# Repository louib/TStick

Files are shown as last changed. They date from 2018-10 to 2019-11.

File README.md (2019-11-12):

# T-Stick Digital Musical Instrument (DMI)

The T-Stick is a DMI conceived by Joseph Malloch and D. Andrew Stewart at the Input Devices and Music Interaction Laboratory (IDMIL) at McGill University. It has been in development since 2006, has a relatively long history for a DMI, has multiple versions, several expert performers, and has an associated repertoire. More than 20 copies have been built unintended for commercial use. Nevertheless, it has been adopted by expert performers and composers as part of their musical practice including D. Andrew Stewart (Soprano user) and Fernando Rocha (Tenor user). It has appeared in dozens of public appearances in countries such as Canada, USA, Brazil, Italy, Norway, and Portugal.

This repository hosts up to date firmware for the instruments currently  at the IDMIL. Driver and Instrument patches in Max/MSP. Spec Sheets and Schematics for all instruments.

## Documentation:

[T-Stick connection guide – v1.1 for wireless T-Sticks](./Sopranino/2GW/FW19101/Docs/T-Stick_2GW_Connecting_Guide(v1.1).md) (model [2GW-19X](./Sopranino/2GW/FW19101/README.md))

[How to build a T-Stick Sopranino](./Sopranino/2GW/FW19101/Docs/T-Stick_2GW_building_instructions.md)

## Instruments:

As of October 2019 there are 13 instruments at [IDMIL](http://www.idmil.org):

- 01 T-Stick Tenor (2G)
- 06 T-Stick Sopranos (2G, 2GX, 2G-IMU)
- 01 T-Stick Sopranino (2G)
- 05 wireless T-Stick Sopraninos (2G, 2GW)

## Project info:

Project webpage at IDMIL: http://www-new.idmil.org/project/the-t-stick/

Official repository: https://github.com/IDMIL/TStick

IDMIL - Input Devices and Music Interaction Laboratory - http://www-new.idmil.org/ \
CIRMMT - Centre for Interdisciplinary Research in Music Media and Technology - http://www.cirmmt.org/ \
Schulich School of Music - McGill University

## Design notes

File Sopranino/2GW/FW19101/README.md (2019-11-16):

# T-Stick 2GW (Firmware version: 19101)

- [Firmware upload instructions](#firmware-upload-instructions)
	* [Option 1: using .bin files and esptool.py](#option-1-using-bin-files-and-esptoolpy)
	* [Option 2: Using Arduino IDE](#option-2-using-arduino-ide)
- [Other Documentation](#other-documentation)
- [Firmware information](#firmware-information)

##  Firmware upload instructions:

###  Option 1: using .bin files and esptool.py

This method is easier/faster. It uses [esptool.py](https://github.com/espressif/esptool). 

##### Download [esptool.py](https://github.com/espressif/esptool):

- Download the _esptool.py_ from https://github.com/espressif/esptool. Use the `Download ZIP` option from Github
- Unzip the _esptool-master.zip_ file

##### Connect the T-Stick to the computer and check the USB port:

- [Check the T-Stick (ESP32) port in your computer](https://docs.espressif.com/projects/esp-idf/en/latest/get-started/establish-serial-connection.html):
  - For MacOS/Linux:
    - Open a _Terminal_ window
    - Execute the command `ls /dev/cu.*`. The command will return a list of ports in your computer.
    - Plug the T-Stick (USB) and run the command `ls /dev/cu.*` one more time. You can now compare the lists and anotate the T-Stick USB port. Should be something similar to `/dev/cu.wchusbserial1410`, probably with a different number
    - Linux users should also give the currently logged user read and write access the serial port over USB.
      Check [here](https://docs.espressif.com/projects/esp-idf/en/latest/get-started/establish-serial-connection.html) for more information
  - For Windows:
    - Check the list of identified COM ports in the [Windows Device Manager](https://support.microsoft.com/en-ca/help/4026149/windows-open-device-manager)
    - Plug the T-Stick (USB) and check the list of identified COM ports in the [Windows Device Manager](https://support.microsoft.com/en-ca/help/4026149/windows-open-device-manager) again. The T-Stick port should appear on the list. Anotate the T-Stick USB port, it should be something similar to `COM3` or `COM16`

##### Flash the firmware (.bin files):

- Use _Finder_ or _Terminal_ to copy the contents of the [bin](./bin/) folder (you should copy 5 .bin files) to the _esptool-master_ folder
- Navigate to the _esptool-master_ folder in _Terminal_
- Run the command (__don't forget to replace the --port (/dev/cu.wchusbserial1410) option for your T-Stick port__):
  ````
  esptool.py --chip esp32 --port /dev/cu.wchusbserial1410 --baud 115200 --before default_reset --after hard_reset write_flash -z --flash_mode dio --flash_freq 80m --flash_size detect 0xe000 boot_app0.bin 0x1000 bootloader_dio_80m.bin 0x10000 esp32_arduino_19X_19101.ino.bin 0x8000 esp32_arduino_19X_19101.ino.partitions.bin 2686976 esp32_arduino_19X_19101.spiffs.bin
  ```
  Wait for the process to be complete. Do not unplug or turn off your T-Stick during the process.
- Your T-Stick will have default information. You need to connect with the instrument (see the [T-Stick Connecting Guide](./Docs/T-Stick_2GW_Connecting_Guide(v1.1).md)) and change all basic information (device name, author, nickname, and id)

To test if the data is being send correctly:

- Connect the T-Stick to a network (instructions [here](./Docs/T-Stick_2GW_Connecting_Guide(v1.1).md));
- Open the Pure Data (PD) or Max/MSP patch to receive T-Stick messages (they can be found [here](./Configuration));
- Start receive OSC messages according to the chosen patch.

###  Option 2: Using Arduino IDE

_READ ALL DEPENDENCIES AND OBSERVATIONS BEFORE UPLOAD !_

##### Install Arduino IDE:

To download and install Arduino IDE, follow the instructions at https://www.arduino.cc/en/main/software.

##### Install Arduino ESP32 filesystem uploader: 

You need to upload a file (data/config.json) into ESP32 filesystem. 
Follow the instructions at https://github.com/me-no-dev/arduino-esp32fs-plugin.

##### Install all depencencies:

1. ESP32 Arduino core 1.0.4 or newer. Instructons at https://github.com/espressif/arduino-esp32/blob/master/docs/arduino-ide/boards_manager.md. Install using [boards manager](https://www.arduino.cc/en/guide/cores)
2. For some systems it may be required to also install the ESP8266 Arduino core. Instructons at https://github.com/esp8266/Arduino. Install using [boards manager](https://www.arduino.cc/en/guide/cores)
3. [Wifi32Manager](https://github.com/edumeneses/WiFi32Manager). Instructons at https://github.com/edumeneses/WiFi32Manager#installing. Install using [manual installation](https://www.arduino.cc/en/guide/libraries#toc5)
4. [Adafruit_LSM9DS1](https://github.com/adafruit/Adafruit_LSM9DS1). Install using [library manager](https://www.arduino.cc/en/guide/libraries#toc3)
5. [ArduinoJSON](https://github.com/bblanchon/ArduinoJson) v6.12 or up. Install using [library manager](https://www.arduino.cc/en/guide/libraries#toc3)
6. [CNMAT OSC library](https://github.com/CNMAT/OSC) v3.5.7 or up. Install using [library manager](https://www.arduino.cc/en/guide/libraries#toc3)
7. [DocSunset MIMU Library](https://github.com/DocSunset/MIMU). Install using [manual installation](https://www.arduino.cc/en/guide/libraries#toc5)
8. [Eigen linear algebra library for Arduino](https://github.com/bolderflight/Eigen). Install using [manual installation](https://www.arduino.cc/en/guide/libraries#toc5)

Observations:

1. MINU library complains if you keep any IMU-related files other than MIMU_LSM9DS1.h and MIMU_LSM9DS1.cpp
2. Microcontroller currently in use for T-Stick 2GW: [Wemos LOLIN D32 PRO](https://wiki.wemos.cc/products:d32:d32_pro)

##### Create your custom config.json file:

Each T-Stick uses a _config.json_ file to store all configuration paramethers.

- Make the necessary changes to the [_config.json_](./esp32_arduino_19X_19101/data/config.json) file:
  - device: replace _color_ with the shrinking material color, and _19X_ with T-stick's serial number
  - author: replace _IDMIL_ with the builder's name (or alias)
  - nickname: replace _color_ with the shrinking material color
  - id: replace _190_ with your T-Stick serial number
- Save the file at the _data_ folder (inside _esp32_arduino_19X_19101_). Make sure _config.json_ is the only file at _data_ folder

##### Upload (flash) the firmware and config.json into the T-Stick:

- Open the file `esp32_arduino_19X_19101.ino` using Arduino IDE
- Choose the proper _board_: `Tools -> Board: "*******" -> LOLIN D32 PRO`
- Choose Upload Speed: `Tools -> Upload Speed: "******" -> 115200`
- Choose port:
  - Keep the T-Stick disconnected to the computer
  - Go to: `Tools -> Port` and take note the available ports
  - connect the T-Stick to the computer using an USB cable and turn the T-Stick ON
  - Go to: `Tools -> Port` and choose the new available port (T-Stick port)
- Upload the firmware: `Sketch -> Upload`. Do not disconnect or turn the T-Stick off during the upload process
- Upload _config.json_: `Tools -> ESP32 Sketch Data Upload`. Do not disconnect or turn the T-Stick off during the upload process

##### Test T-Stick:

To test your T-Stick after flashing firmware/config.json, you can use Arduino IDE:

- Choose T-Stick serial port
- Open the _Serial Monitor_ (`Tools -> Serial Monitor`)

You should see T-Stick booting process.

To test if the data is being send correctly:

- Connect the T-Stick to a network (instructions [here](./Docs/T-Stick_2GW_Connecting_Guide(v1.1).md))
- Open the Pure Data (PD) or Max/MSP patch to receive T-Stick messages (they can be found [here](./Configuration))
- Start receive OSC messages according to the chosen patch

##  Other Documentation:

[T-Stick connection guide – v1.1 for wireless T-Sticks](./Docs/T-Stick_2GW_Connecting_Guide(v1.1).md) (model 2GW-19X)

[How to build a T-Stick Sopranino](./Docs/T-Stick_2GW_building_instructions.md)

##  Firmware information:

Sopranino T-Stick 2GW - LOLIN D32 PRO - USB -WiFi  
Input Devices and Music Interaction Laboratory (IDMIL)  
Created: February 2018 by Alex Nieva  
October 2019 by Edu Meneses - firmware version 19101 (2019-10.v1)  
Notes: Based on test program for reading CY8C201xx using I2C by Joseph Malloch 2011  
Adapted to work with Arduino IDE 1.8.10 and T-Stick Sopranino 2GW  

WiFi32Manager - For use with ESP8266 or ESP32  
Created originally for the T-Stick project:  
http://www-new.idmil.org/project/the-t-stick/  
This code uses code (fork) of 3 other projects:  
https://github.com/kentaylor/WiFiManager    
https://github.com/tzapu/WiFiManager  
https://github.com/zhouhan0126/WIFIMANAGER-ESP32    
Edu Meneses - IDMIL - Mar 2019    

MIMU - Magnetometer + accelerometer + gyroscope orientation library  
https://github.com/DocSunset/MIMU  
Travis West - IDMIL - Oct 2019

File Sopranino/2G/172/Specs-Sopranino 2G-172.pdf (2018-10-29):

## T-Stick Sopranino 2G

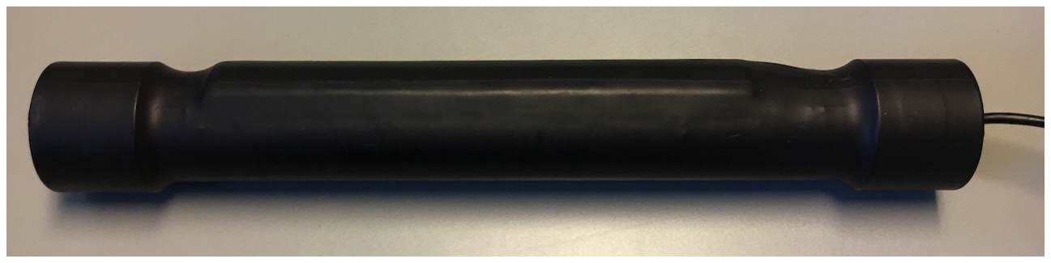
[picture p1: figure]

Specifications:

- Touch Sensing: 16 capacitive sensing strips
- Motion Sensing: 3-axis digital accelerometer
- Pressure Sensing: 1 Force Sensitive Resistor
- Shock Sensing: 1 Piezoelectric senor
- Connectivity: USB 2.0 Mini Type-B
- Dimensions: 35cm x 5cm (diameter)
- Weight: 0.311 Kg
- Serial Number: 172

Requirements:

- Mac OSX with Max/MSP
- Libmapper externals for Max/MSP
- Sound Synthesizers that work with libmapper: granul8, modal.
- Other sound synthesizers to create ad-hoc mappings.

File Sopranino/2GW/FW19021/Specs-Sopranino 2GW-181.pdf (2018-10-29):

## T-Stick Sopranino 2GW

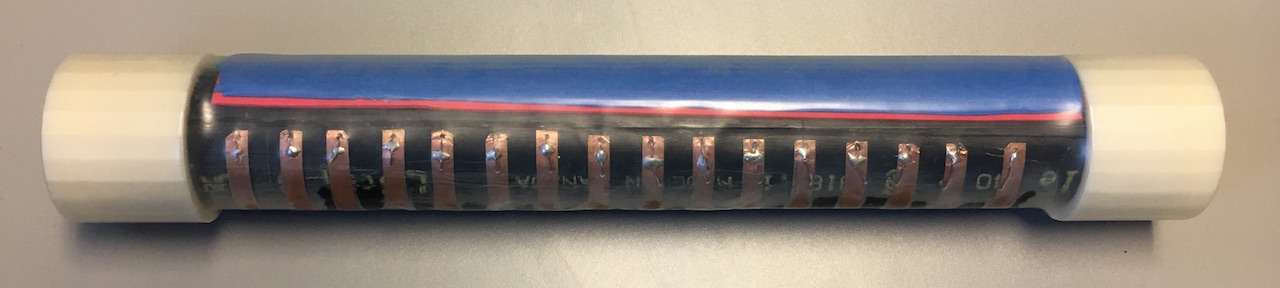
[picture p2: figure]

Specifications:

- Touch Sensing: 16 capacitive sensing strips
- Motion Sensing: 9 DOF IMU
- Pressure Sensing: 1 Force Sensitive Resistor
- Connectivity: WiFi – OSC based data communication
- Dimensions: 33.5cm x 5cm (diameter)
- Weight: 0.3 Kg
- Serial Number: 181

Requirements:

- Mac OSX with Max/MSP
- Libmapper externals for Max/MSP
- Sound Synthesizers that work with libmapper: granul8, modal.
- Other sound synthesizers to create ad-hoc mappings.

OSC Namespace

Send | Variable type
/information | (2) unsigned int
/rawcapsense | (2) int
/rawgyro | (3) float
/rawaccel | (3) float
/rawmag | (3) float
/rawpressure | (1) unsigned int

Receive | Variable type/Description
/status | (4) int
/status 115 | Heartbeat every 1.5sec
/status 120 | Stop
/status 119 105 i i | Write info: Serial #, Firmware Rev.
/status 119 84 i i | Touch Mask
/status 99 i | Calibration of FSR
/status 119 119 | Write Settings EEPROM
/status 119 114 | Read Settings EEPROM

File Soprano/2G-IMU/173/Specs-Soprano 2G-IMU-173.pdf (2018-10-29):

## T-Stick Soprano 2G-IMU

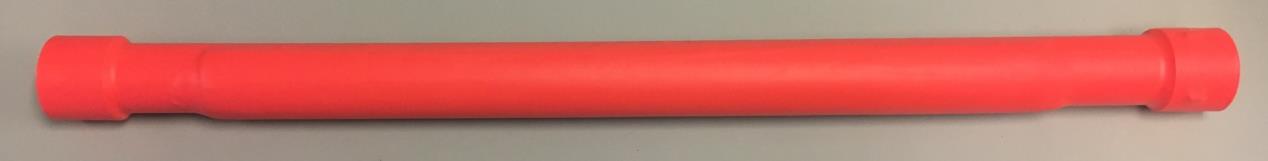
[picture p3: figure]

Specifications:

- Touch Sensing: 48 capacitive sensing strips
- Motion Sensing: 9 DOF IMU
- Pressure Sensing: 1 Force Sensitive Resistor (paper-based)
- Shock Sensing: 1 Piezoelectric sensor
- Connectivity: USB 2.0 Type-B
- Dimensions: 71cm x 5cm (diameter)
- Weight: 0.595 Kg
- Serial Number: 173

Requirements:

- Mac OSX with Max/MSP
- Libmapper externals for Max/MSP
- Sound Synthesizers that work with libmapper: granul8, modal.
- Other sound synthesizers to create ad-hoc mappings.

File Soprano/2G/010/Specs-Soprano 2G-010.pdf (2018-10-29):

## T-Stick Soprano 2G

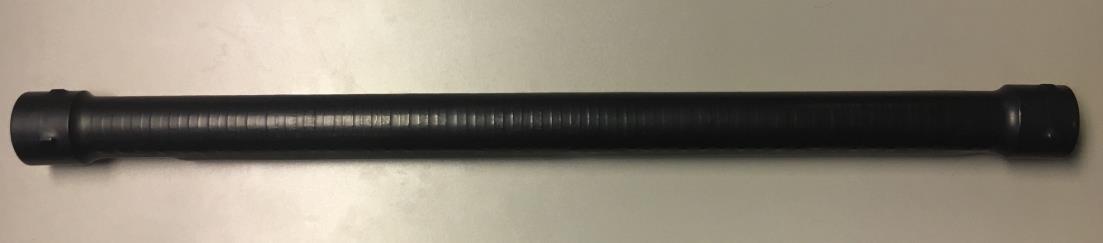
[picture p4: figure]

Specifications:

- Touch Sensing: 48 capacitive sensing strips
- Motion Sensing: 3-axis analogue accelerometer
- Pressure Sensing: 1 Force Sensitive Resistor
- Shock Sensing: 1 Piezoelectric sensor
- Connectivity: USB 2.0 Type-B
- Dimensions: 71cm x 5cm (diameter)
- Weight: 0.571 Kg
- Serial Number: 010

Requirements:

- Mac OSX with Max/MSP
- Libmapper externals for Max/MSP
- Sound Synthesizers that work with libmapper: granul8, modal.
- Other sound synthesizers to create ad-hoc mappings.

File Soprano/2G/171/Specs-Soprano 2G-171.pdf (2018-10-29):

## T-Stick Soprano 2G

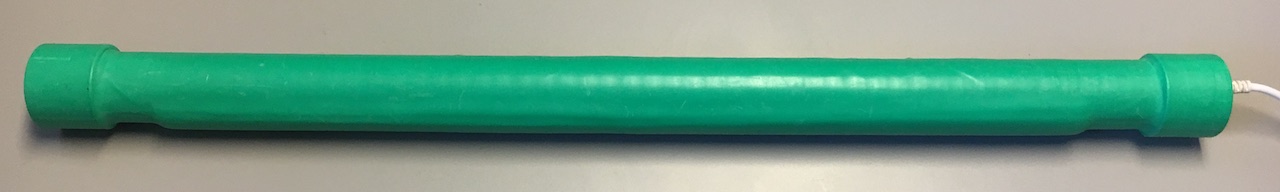
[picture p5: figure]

Specifications:

- Touch Sensing: 48 capacitive sensing strips
- Motion Sensing: 3-axis analog accelerometer
- Pressure Sensing: 1 Force Sensitive Resistor
- Shock Sensing: 1 Piezoelectric sensor
- Connectivity: USB 2.0 Type-B
- Dimensions: 71cm x 5cm (diameter)
- Weight: 0.606 Kg
- Serial Number: 171

Requirements:

- Mac OSX with Max/MSP
- Libmapper externals for Max/MSP
- Sound Synthesizers that work with libmapper: granul8, modal.
- Other sound synthesizers to create ad-hoc mappings.

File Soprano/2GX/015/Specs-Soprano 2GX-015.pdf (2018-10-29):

## T-Stick Soprano 2GX

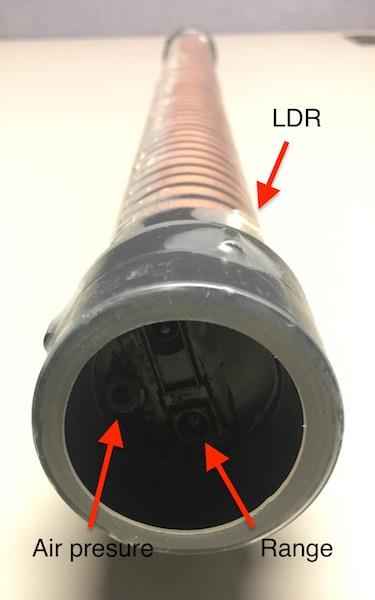
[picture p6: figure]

Specifications:

- Touch Sensing: 48 capacitive sensing strips
- Motion Sensing: 3-axis digital accelerometer
- Pressure Sensing: 1 Force Sensitive Resistor
- Shock Sensing: 1 Piezoelectric sensor
- Light Sensing: 2 LDRs
- Range Sensing: Infrared
- Breath Sensing: Air pressure sensor
- Connectivity: USB 2.0 Type-B
- Dimensions: 71cm x 5cm (diameter)
- Weight: 0.597 Kg
- Serial Number: 171

Requirements:

- Mac OSX with Max/MSP
- Libmapper externals for Max/MSP
- Sound Synthesizers that work with libmapper: granul8, modal.
- Other sound synthesizers to create ad-hoc mappings.

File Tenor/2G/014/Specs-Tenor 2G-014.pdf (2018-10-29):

## T-Stick Tenor 2G

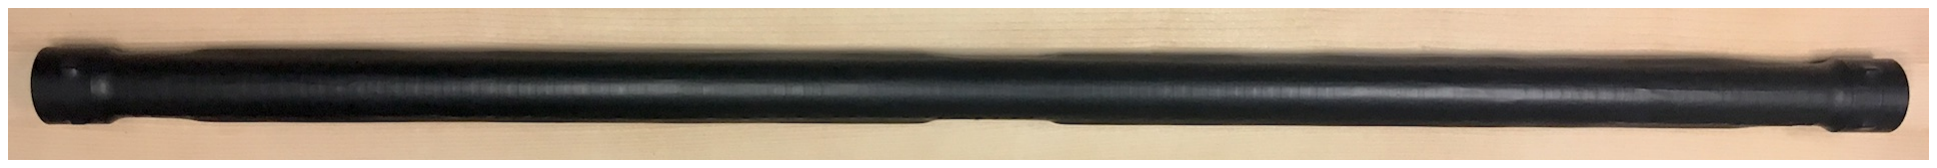
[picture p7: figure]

Specifications:

- Touch Sensing: 96 capacitive sensing strips
- Motion Sensing: 3-axis accelerometer
- Pressure Sensing: 1 Force Sensitive Resistor
- Shock Sensing: 1 Piezoelectric sensor
- Connectivity: USB 2.0 Type-B
- Dimensions: 124.5cm x 5cm (diameter)
- Weight: 0.976 Kg
- Serial Number: 014

Requirements:

- Mac OSX with Max/MSP
- Libmapper externals for Max/MSP
- Sound Synthesizers that work with libmapper: granul8, modal.
- Other sound synthesizers to create ad-hoc mappings.

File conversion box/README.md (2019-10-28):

# T-Stick Conversion Box - Building recipe - Rpi 2B and 3B+

Under Raspbian Lite

## Prepare the OS

- Flash the latest Prynth image (https://prynth.github.io/create/downloads.html)
- Add ssh file to Boot partition: `touch ssh`
- Add wpa_supplicant.conf to file to Boot partition: `vim wpa_supplicant.conf`. File contents:

```bash
ctrl_interface=DIR=/var/run/wpa_supplicant GROUP=netdev
update_config=1
country=US

network={
     ssid="Your network name/SSID"
     psk="Your WPA/WPA2 security key"
     key_mgmt=WPA-PSK
}
```

- Open Prynth software settings at `http://raspberrypi.local:3000/system` and change hostname to match the converted T-Stick  
- SSH, change password, hostname, set country, expand file system (raspi-config)

## Update

```bash
sudo apt-get -y update
sudo apt-get -y dist-upgrade
```

## Install liblo

```bash
sudo apt-get remove -y liblo-dev
mkdir ~/sources
cd ~/sources
git clone https://github.com/radarsat1/liblo.git
cd liblo
sudo apt-get install -y vim autoconf libtool automake
./autogen.sh
make
sudo make install
```

## Install Libmapper

```bash
sudo apt-get install python-dev swig
cd ~/sources
git clone https://github.com/libmapper/libmapper.git
cd libmapper
./autogen.sh
echo 'export LD_LIBRARY_PATH=$LD_LIBRARY_PATH:/usr/local/lib' >> ~/.bashrc
make
sudo make install
```

## Install Webmapper

```bash
pip install netifaces
cd ~/sources
git clone https://github.com/libmapper/webmapper.git
cp ~/sources/libmapper/swig/_mapper.so ~/sources/webmapper
cp ~/sources/libmapper/swig/mapper.py ~/sources/webmapper
cd webmapper/
```

- To run Webmapper: ./webmapper.py

## Install Python 3.7.3

```bash
sudo apt-get install -y build-essential tk-dev libncurses5-dev libncursesw5-dev libreadline6-dev libdb5.3-dev libgdbm-dev libsqlite3-dev libssl-dev libbz2-dev libexpat1-dev liblzma-dev zlib1g-dev libffi-dev apt-show-versions
cd ~/sources
wget https://www.python.org/ftp/python/3.7.3/Python-3.7.3.tgz
tar -zxvf Python-3.7.3.tgz
cd Python-3.7.3/
./configure --enable-optimizations
make -j4
make test
sudo make install
```

Reboot

## Create python application to read serial port and send OSC messages

- Install packages:

```bash
cd ~
sudo apt-get install -y python3-pip python-pip setserial
sudo pip3 install python-osc pyserial apscheduler bitstring netifaces
pip install pyserial apscheduler bitstring pyOSC netifaces oscpy
mkdir tstick
```

- Create code:

```bash
cat <<- "EOF" | sudo tee ~/tstick/tstick.py
# Python code to convert T-Stick serial port messages to OSC
# Author: Edu Meneses (IDMIL, 2019)

import sys
import serial
import collections
from apscheduler.schedulers.background import BackgroundScheduler
from bitstring import BitArray
import netifaces as ni

import argparse
from pythonosc import osc_message_builder
from pythonosc import udp_client
from pythonosc.dispatcher import Dispatcher

from pythonosc.osc_server import AsyncIOOSCUDPServer
import asyncio

# parse argument to set OSC to send/receive T-Stick data
parser = argparse.ArgumentParser(
    description='Convert T-Stick serial port messages into OSC messages.',
    formatter_class=argparse.ArgumentDefaultsHelpFormatter)
parser.add_argument("--serialport", "-s", default="/dev/ttyUSB0",
                    metavar='', help="The T-Stick's serial port")
parser.add_argument("--ip", "-i", default="192.168.0.1",
                    metavar='', help="The ip of the OSC server")
parser.add_argument("--port", "-p", type=int, default=8000,
                    metavar='', help="The port the OSC server is listening on")
parser.add_argument("--networkinterface", "-n", default="wlan0",
                    metavar='', help="The interface connected to the network")
parser.add_argument("--listenport", "-l", type=int, default=8888,
                    metavar='', help="The port this machine is listening on")
args = parser.parse_args()

# set listening ip to receive OSC messages
ni.ifaddresses(args.networkinterface)
local_ip = ni.ifaddresses(args.networkinterface)[ni.AF_INET][0]['addr']

# Opening T-Stick serial port
tstick = serial.Serial(args.serialport, 115200, dsrdtr=1)

# checking system byteorder
byteorder = sys.byteorder

# creating global variable to define T-Stick mapping
tstick_id = 0

dispatcher = Dispatcher()

client_OSC = udp_client.SimpleUDPClient(args.ip, args.port)

def resend(address, *args):
    tstick.write(args)

def heartbeat():
    tstick.write('s'.encode('utf-8'))

async def receive_serial():
    flag = False
    msg = []
    while True:
        byte = int.from_bytes(tstick.read(), byteorder)
        if not flag:
            if byte == 100:
                get_tstick_id(*msg)
                if(tstick_id == 173):
                    sort_and_send_173(*msg)
                elif(tstick_id == 10 or
                     tstick_id == 12 or
                     tstick_id == 24 or
                     tstick_id == 171):
                    sort_and_send_2G(*msg)
                elif(tstick_id == 15):
                    sort_and_send_2GX(*msg)
                msg.clear()
            elif byte == 101:
                flag = True
            else:
                msg.append(byte)
        else:
            msg.append(byte)
            flag = False
        await asyncio.sleep(0)

# 'convert' 10 bits
def bit_conversion(byte1, byte2):
    return (byte1 * 256) + byte2

# T-stick 16 bit conversion IMU
def bit_ext_conversion(byte1, byte2):
    bin_or = (byte1 * 256) | byte2
    return bin_or - (65535 * (bin_or > 32767))

def get_tstick_id(*msg):
    if msg[0] == 0:
        if len(msg) < 3:
            return 0
        global tstick_id
        tstick_id = bit_conversion(msg[1], msg[2])
        firmware = bit_conversion(msg[3], msg[4])
        info_list = [tstick_id, firmware]
        if len(msg) > 5:
            for i in msg[5:]:
                info_list.append(i)
        client_OSC.send_message("/information", info_list)
        return tstick_id

# route T-Stick messages for T-Stick #173
def sort_and_send_173(*msg):
    if msg[0] == 0:
        pass
    elif msg[0] == 1:
        rawcapsense = msg[1:]
        client_OSC.send_message("/rawcapsense", rawcapsense)
        # capsense_bits = cook_touch_soprano(*rawcapsense)
    elif msg[0] == 2:
        accel_x = bit_ext_conversion(msg[1], msg[2])
        accel_y = bit_ext_conversion(msg[3], msg[4])
        accel_z = bit_ext_conversion(msg[5], msg[6])
        gyro_x = bit_ext_conversion(msg[7], msg[8])
        gyro_y = bit_ext_conversion(msg[9], msg[10])
        gyro_z = bit_ext_conversion(msg[11], msg[12])
        pressure = bit_ext_conversion(msg[13], msg[14])
        piezo = bit_ext_conversion(msg[15], msg[16])
        client_OSC.send_message("/rawaccel", [accel_x, accel_y, accel_z])
        client_OSC.send_message("/rawgyro", [gyro_x, gyro_y, gyro_z])
        client_OSC.send_message("/rawpressure", pressure)
        client_OSC.send_message("/rawpiezo", piezo)
    elif msg[0] == 3:
        mag_x = bit_ext_conversion(msg[1], msg[2])
        mag_y = bit_ext_conversion(msg[3], msg[4])
        mag_z = bit_ext_conversion(msg[5], msg[6])
        client_OSC.send_message("/rawmag", [mag_x, mag_y, mag_z])
    elif msg[0] == 4:
        return 0

# route T-Stick messages for T-Stick 2G series: 010, 012, 024, 171
def sort_and_send_2G(*msg):
    if msg[0] == 0:
        pass
    elif msg[0] == 1:
        rawcapsense = msg[1:]
        client_OSC.send_message("/rawcapsense", rawcapsense)
        # capsense_bits = cook_touch_soprano(*rawcapsense)
    elif msg[0] == 2:
        rawjab = msg[1:]
        client_OSC.send_message("/rawjab", rawjab)
    elif msg[0] == 3:
        rawtap = msg[1:]
        client_OSC.send_message("/rawtap", rawtap)
    elif msg[0] == 4:
        accel_x = bit_conversion(msg[1], msg[2])
        accel_y = bit_conversion(msg[3], msg[4])
        accel_z = bit_conversion(msg[5], msg[6])
        pressure = bit_conversion(msg[7], msg[8])
        piezo = bit_conversion(msg[9], msg[10])
        client_OSC.send_message("/rawaccel", [accel_x, accel_y, accel_z])
        client_OSC.send_message("/rawpressure", pressure)
        client_OSC.send_message("/rawpiezo", piezo)

# route T-Stick messages for T-Stick #015
def sort_and_send_2GX(*msg):
    if msg[0] == 0:
        pass
    elif msg[0] == 1:
        rawcapsense = msg[1:]
        client_OSC.send_message("/rawcapsense", rawcapsense)
        # capsense_bits = cook_touch_soprano(*rawcapsense)
    elif msg[0] == 2:
        rawjab = msg[1:]
        client_OSC.send_message("/rawjab", rawjab)
    elif msg[0] == 3:
        rawtap = msg[1:]
        client_OSC.send_message("/rawtap", rawtap)
    elif msg[0] == 4:
        accel_x = bit_conversion(msg[1], msg[2])
        accel_y = bit_conversion(msg[3], msg[4])
        accel_z = bit_conversion(msg[5], msg[6])
        pressure = bit_conversion(msg[7], msg[8])
        piezo = bit_conversion(msg[9], msg[10])
        airpressure = bit_conversion(msg[11], msg[12])
        tstick_range = bit_conversion(msg[13], msg[14])
        ldr1 = bit_conversion(msg[15], msg[16])
        ldr2 = bit_conversion(msg[17], msg[18])
        client_OSC.send_message("/rawaccel", [accel_x, accel_y, accel_z])
        client_OSC.send_message("/rawpressure", pressure)
        client_OSC.send_message("/rawpiezo", piezo)
        client_OSC.send_message("/rawairpressure", airpressure)
        client_OSC.send_message("/rawrange", tstick_range)
        client_OSC.send_message("/rawldr1", ldr1)
        client_OSC.send_message("/rawldr2", ldr2)

# make bit list - 1 per cap stripe
def cook_touch_soprano(*bytes):
    byte_list = ""
    for byte in bytes:
        byte_list = byte_list + format(byte, '08b')
    return list(byte_list)

# setting heartbeat to run every second
def tstick_wakeup():
    scheduler = BackgroundScheduler()
    scheduler.add_job(heartbeat, 'interval', seconds=1)
    scheduler.start()

async def init_main():
    # Create datagram endpoint and start serving
    server_OSC = AsyncIOOSCUDPServer(
        (local_ip, args.listenport), dispatcher, asyncio.get_event_loop())

    transport, protocol = await server_OSC.create_serve_endpoint()

    dispatcher.map("/status", resend)

    tstick_wakeup()

    await receive_serial()

    transport.close()  # Clean up serve endpoint

    sys.exit()

asyncio.run(init_main())  # Init and enter main loop of program

EOF

```
Set the code to load at boot:

```bash
cat <<- "EOF" | sudo tee /lib/systemd/system/tstick.service
[Unit]
Description=T-Stick serial port to OSC conversion

[Service]
ExecStart=/usr/bin/python3 /home/pi/tstick/tstick.py
#User=pi

[Install]
WantedBy=multi-user.target
EOF

```

```bash
sudo systemctl daemon-reload &&\
sudo systemctl enable hardwarecontrol.service
```

Old, unnecessary packages are removed after the system update with the following commands:

```bash
sudo apt-get autoremove
sudo apt-get autoclean
```

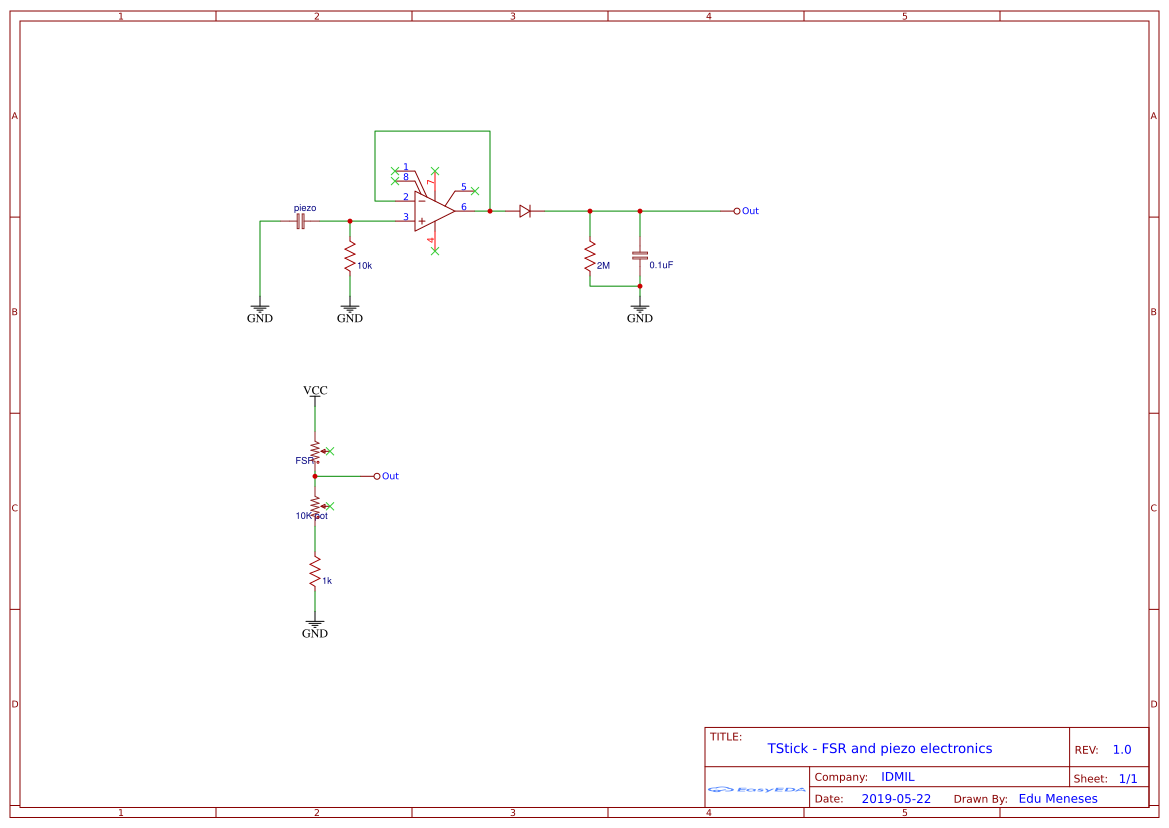
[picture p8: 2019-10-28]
Eagle Libraries/Schematic_T-Stick-FSR-and-Piezo-Electronics_Sheet-1_20190523141905.png

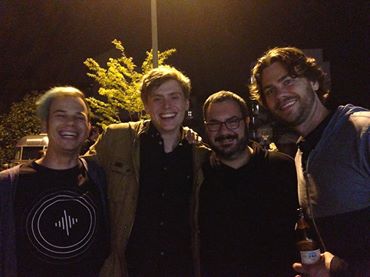
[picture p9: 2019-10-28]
Sopranino/2GW/FW19101/Docs/MUMT620-t-stick_files/13260085_999672986780494_467111662232022858_n.jpg

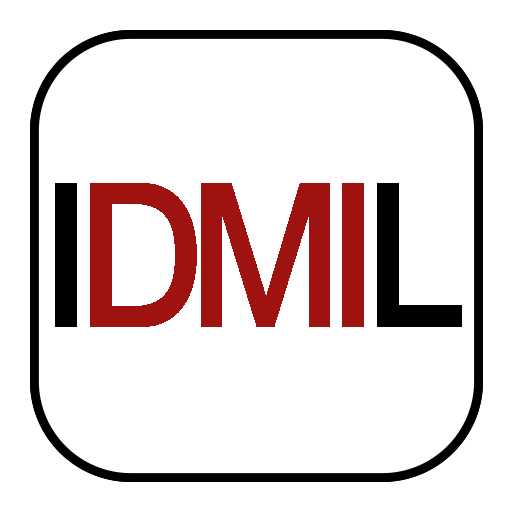
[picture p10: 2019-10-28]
Sopranino/2GW/FW19101/Docs/MUMT620-t-stick_files/cropped-IDMIL-sq-rnd.png

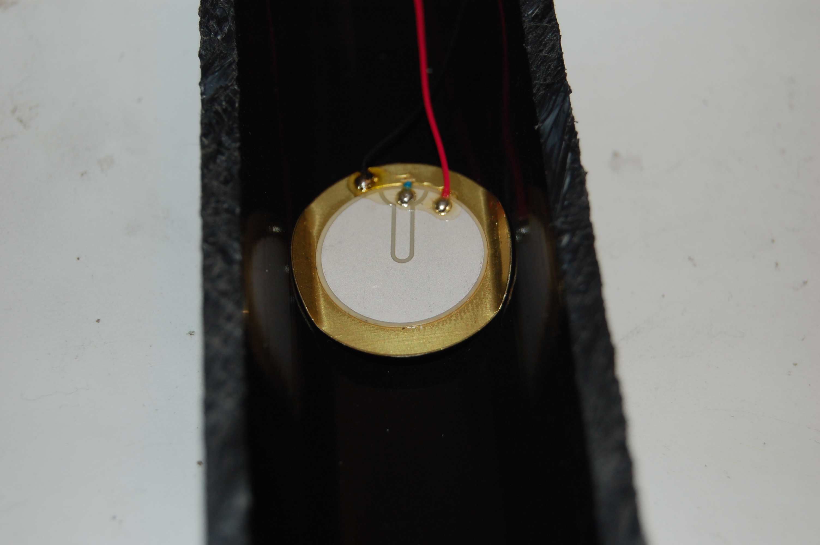
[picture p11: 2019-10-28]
Sopranino/2GW/FW19101/Docs/images/piezo_in_place_v.jpg

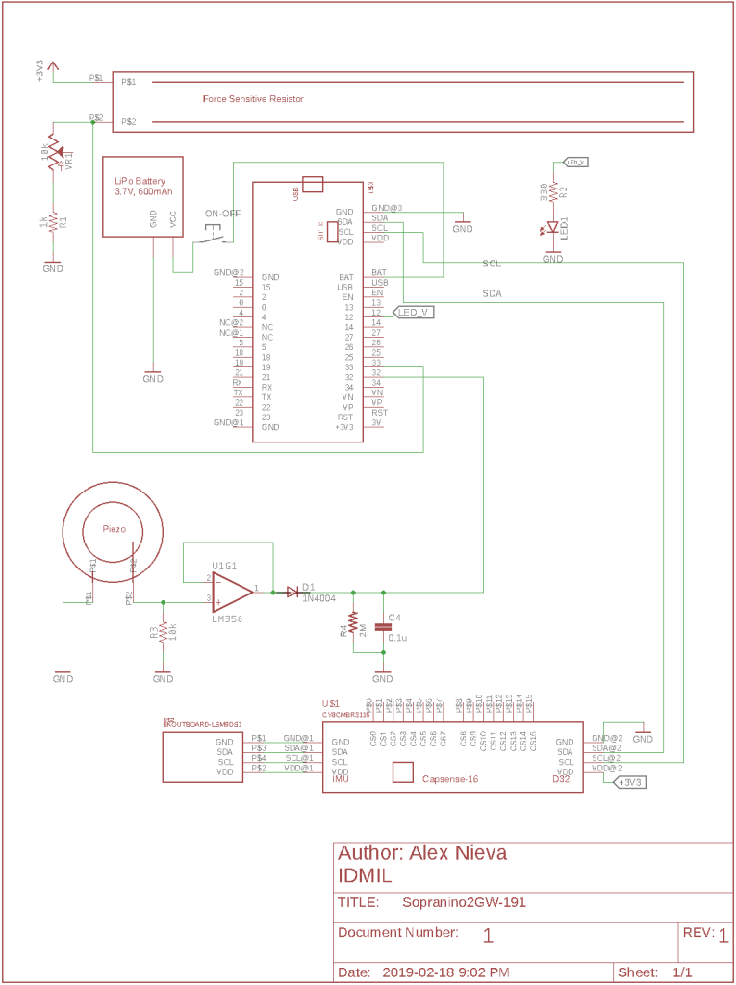
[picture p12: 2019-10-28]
Sopranino/2GW/FW19101/Docs/MUMT620-t-stick_files/Sopranino2GW-191-1.png

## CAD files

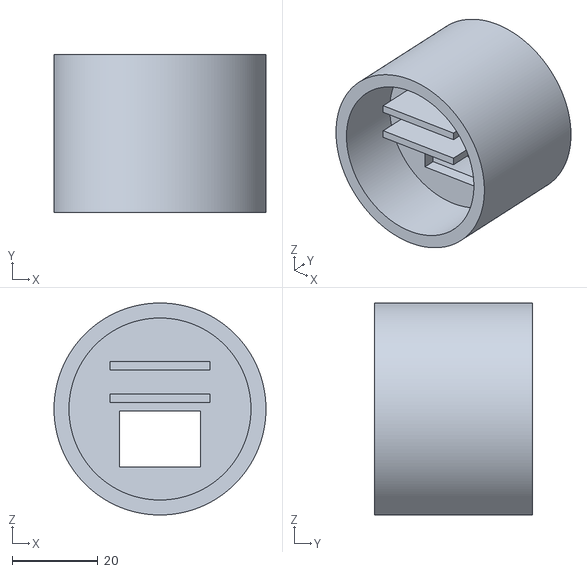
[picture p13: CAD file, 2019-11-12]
3D printed parts/2019_11_09_T-Stick_battery_cap(19X).stl
49.5 x 37.0 x 49.5

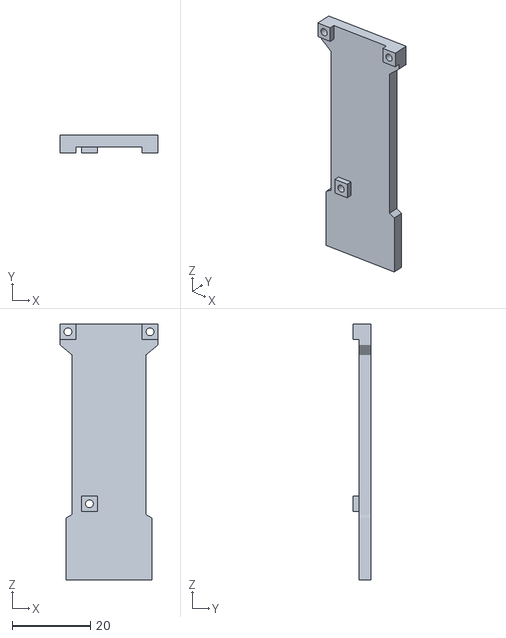
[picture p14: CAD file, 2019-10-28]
3D printed parts/2019_07_05_T-Stick_bed_cap.stl
25.0 x 4.50 x 65.5

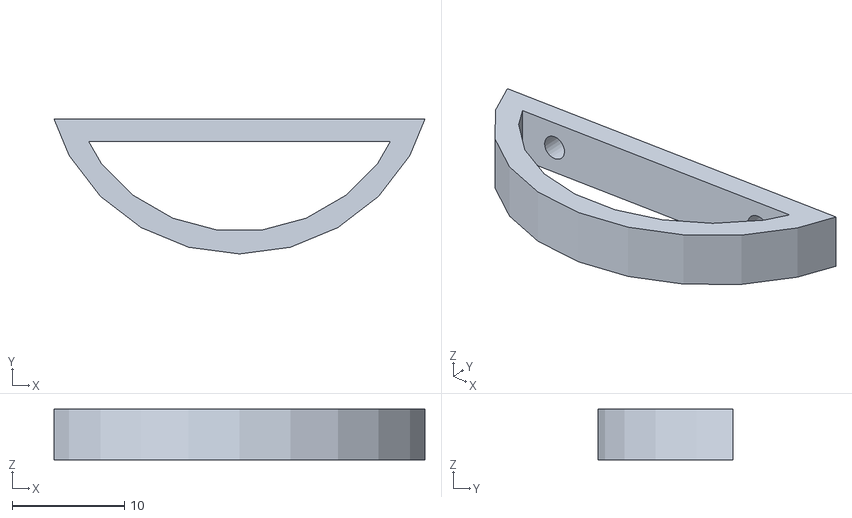
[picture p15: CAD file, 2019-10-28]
3D printed parts/base_Capsense(CY8CMBR3116).stl
33.0 x 12.0 x 4.50

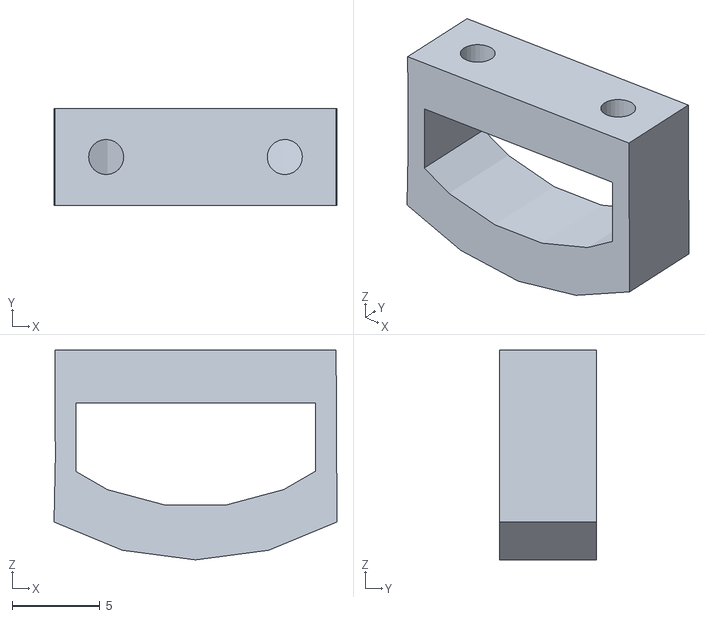
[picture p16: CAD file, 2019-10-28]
3D printed parts/base_IMU(LSM9DS1).stl
16.1 x 5.50 x 11.9

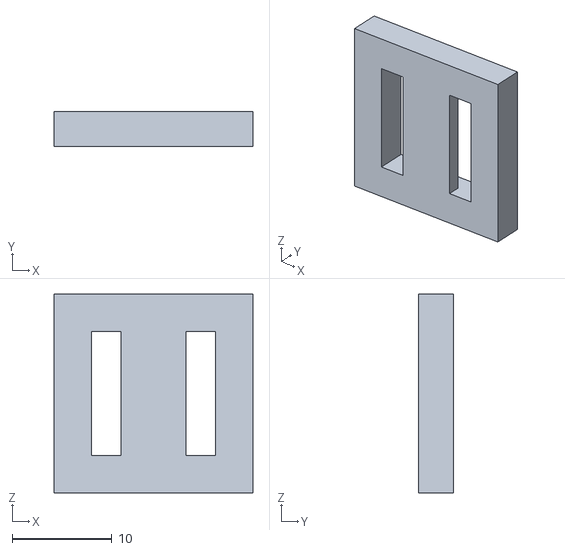
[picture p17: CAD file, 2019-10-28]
3D printed parts/fast_print_button_holder.stl
20.0 x 3.50 x 20.0

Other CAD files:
3D printed parts/2019_07_05_T-Stick_esp_cap.stl
3D printed parts/2019_07_05_tstick_cap v71(Fusion360).f3d
3D printed parts/2019_11_09_tstick_cap v74(Fusion360).f3d

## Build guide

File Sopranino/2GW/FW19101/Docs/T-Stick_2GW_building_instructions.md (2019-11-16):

# Building a Sopranino T-Stick (v1.1)

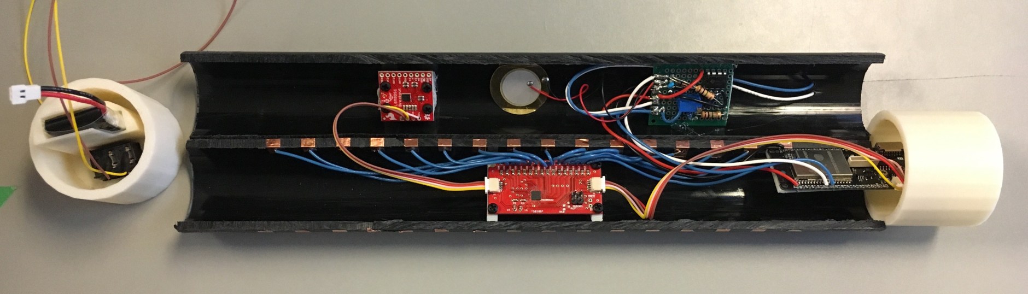
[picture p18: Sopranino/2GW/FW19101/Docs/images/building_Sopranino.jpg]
building_Sopranino image Building a Sopranino T-Stick


## Bill of Materials:

Qty   | Type                | Description 
------|---------------------|-----------------------------------------------------------------------------------
01    | sensor              | [Capsense breakout board (CY8CMBR3116)](https://www.cypress.com/le/127221/download)
01    | sensor              | [IMU breakout board LSM9DS](https://www.sparkfun.com/products/13284)
01    | sensor              | [FSR 408](https://www.robotshop.com/ca/en/interlink-24-long-fsr.html)
01    | sensor              | [buzz elem. piezo STD](https://www.digikey.ca/product-detail/en/cui-inc/CEB-20D64/102-1126-ND/412385)
01    | electronics         | [microcontroller Lolin D32 Pro](https://wiki.wemos.cc/products:d32:d32_pro)
01    | electronics         | [0.1uF capacitor](https://www.digikey.ca/product-detail/en/kemet/C320C104J5R5TA7301/399-9867-1-ND/3726105)
01    | electronics         | 1K resistor
01    | electronics         | [10K resistor](https://www.digikey.ca/product-detail/en/CFM12JT10K0/S10KHCT-ND/2617547/?itemSeq=307630589)
01    | electronics         | [2M resistor](https://www.digikey.ca/product-detail/en/CFM12JT2M00/S2MHCT-ND/2617413/?itemSeq=307631009)
01    | electronics         | [Diode 1N4004](https://www.digikey.ca/product-detail/en/1N4004-TP/1N4004-TPMSCT-ND/773691/?itemSeq=307634719)
01    | electronics         | [10K potentiometer](https://www.digikey.com/products/en?mpart=PV36W103C01B00&v=118)
01    | electronics         | [LM358P Opamp](https://www.digikey.ca/products/en?keywords=296-1395-5-ND)
01    | electronics         | [button](https://www.digikey.ca/product-detail/en/c-k/PTS125SM43-2-LFS/CKN9100-ND/1146743)
02    | electronics         | [SH1.0mm cables](https://www.aliexpress.com/item/32877217306.html)
02    | electronics         | [Breadboards](https://www.digikey.ca/product-detail/en/sparkfun-electronics/PRT-08808/1568-1652-ND/7387401)
30cm  | manufacturing parts | PVC Tube split in 2 lenghtwise
~85cm | manufacturing parts | Copper adhesive tape
01    | manufacturing parts | Li-Po Battery (min 1000mA)
01    | manufacturing parts | [ON-OFF rocker switch](https://www.digikey.ca/product-detail/en/RA1113112R/EG5619-ND/3778055/?itemSeq=307636370)
~35cm | manufacturing parts | Heat shrink tube
01    | manufacturing parts | end-cup with microcontroller base
01    | manufacturing parts | end-cup with for the ON-OFF switch and hold battery
02    | manufacturing parts | 3D printed bases for Capsense
02    | manufacturing parts | [3D printed bases for IMU](/images/SopraninoIMUparts.jpg)
11    | manufacturing parts | [M2 Mounting Screws](https://www.digikey.ca/product-detail/en/MPMS+002+0008+PH/H739-ND/274950/?itemSeq=307635387)
11    | manufacturing parts | [M2 bolts](https://www.digikey.ca/product-detail/en/MHNZ+002+4/H761-ND/274972/?itemSeq=307635458)
01    | manufacturing parts | [foam sheet](https://www.amazon.ca/Craft-Foam-Sheets-Assorted-Colours/dp/B005EQPRM6)

## Schematic:

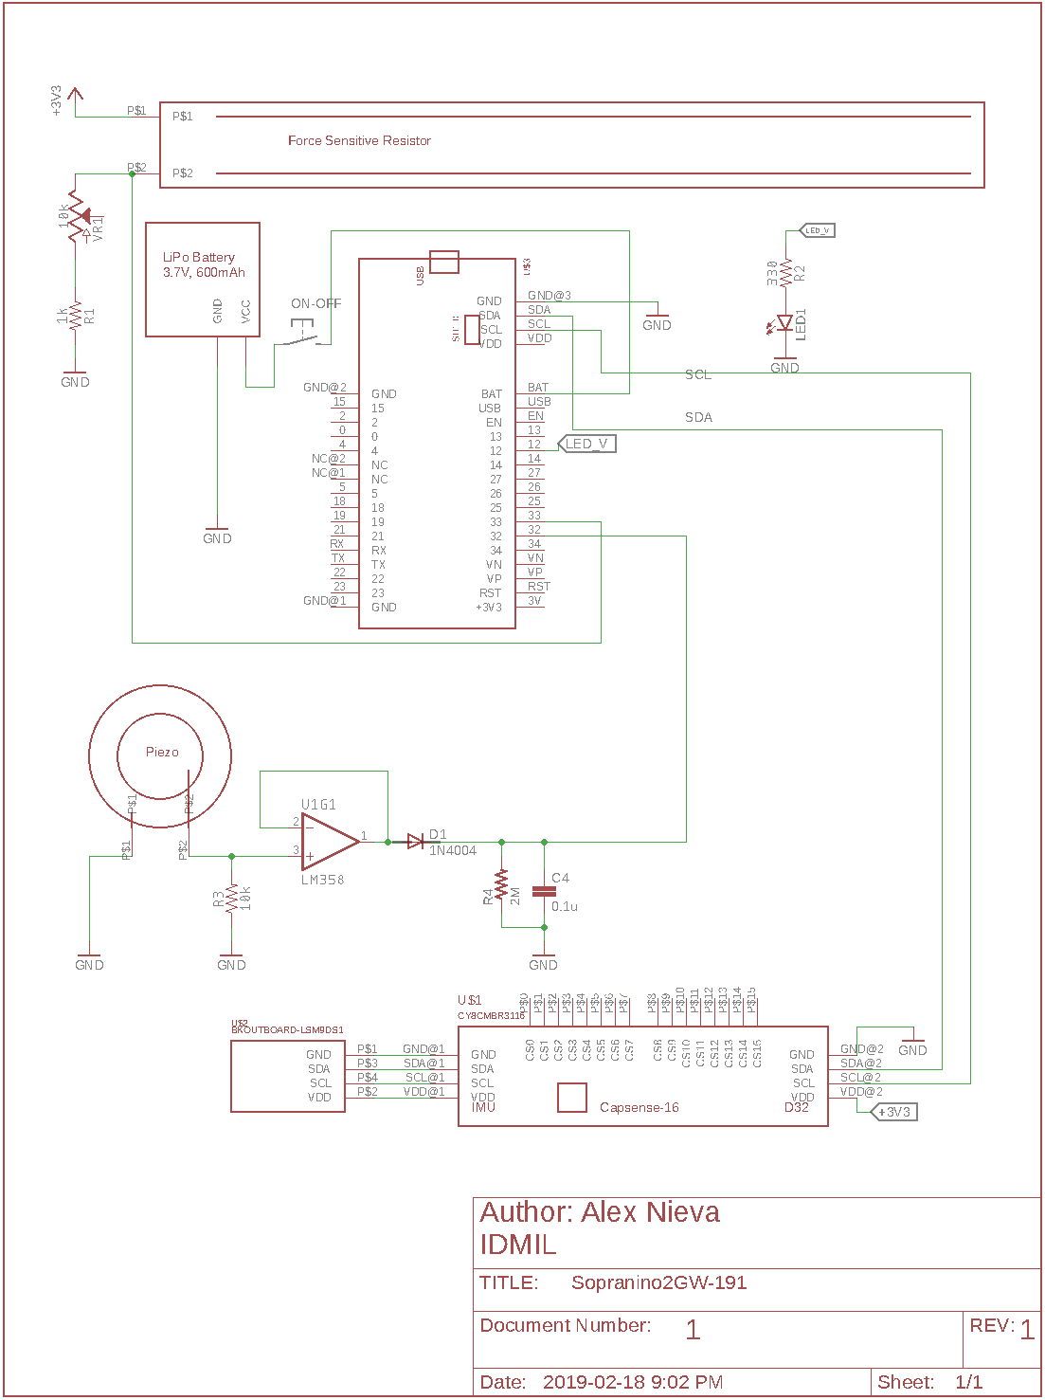
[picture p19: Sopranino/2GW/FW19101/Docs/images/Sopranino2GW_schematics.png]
T-Stick Sopranino schematics


This schematic is outdated. Use for FSR and Piezo Electronics reference only.

## Instructions:

#### Building the Frame:

Cut the PVC in half as in the picture and tape the conductive tape 1.5cm apart. 
Length of holes assembly is 1.5 * 15 for 16 strips. That is 22.5cm. You need aprox. 8 cm of copper tape per strip.

The Capsense (https://www.cypress.com/le/127221/download) breakout boards use 2 3D printed bases.
It connects via a jumper cable with SH1.0mm connectors to the D32 Pro (https://wiki.wemos.cc/products:d32:d32_pro).

__CAUTION__: THE CAPSENSE BOARD HAS THE CONNECTORS LABELED FOR THE IMU AND MICROCONTROLLER (Black marker). BE CAREFUL WHEN CONNECTING THEM BECAUSE OF A LAST MINUTE CHANGE IN THE PINOUT OF THE BOARD. SEE SCHEMATIC BELOW. 

The Capsense label for ground and +3V3 is inverted at the end that goes to the IMU. You should connect:

__Capsense -> IMU__
GND ------> +3V3
SDA ------> SDA
SCL ------> SCL
+3V3------> GND

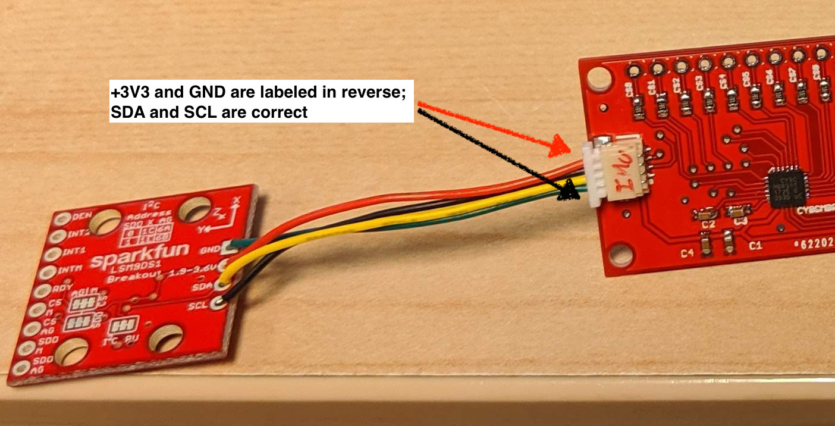
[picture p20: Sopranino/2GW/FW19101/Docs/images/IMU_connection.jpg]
Capsense-IMU connection


Please take extra care since it is necessary to cut the cable and solder the right ends at the IMU.

All the building tools can be found in the Machine Shop at the McGill Music Tech Department.

#### IMU:

The [LSM9DS1](https://www.sparkfun.com/products/13284) IMU connects via another SH1.0mm cable to the other socket on the Capsense for I2C communication.
One end has the SH housing the other is open to solder onto the IMU breakout board. There are also 2 3D printed bases to attach the IMU to the frame.

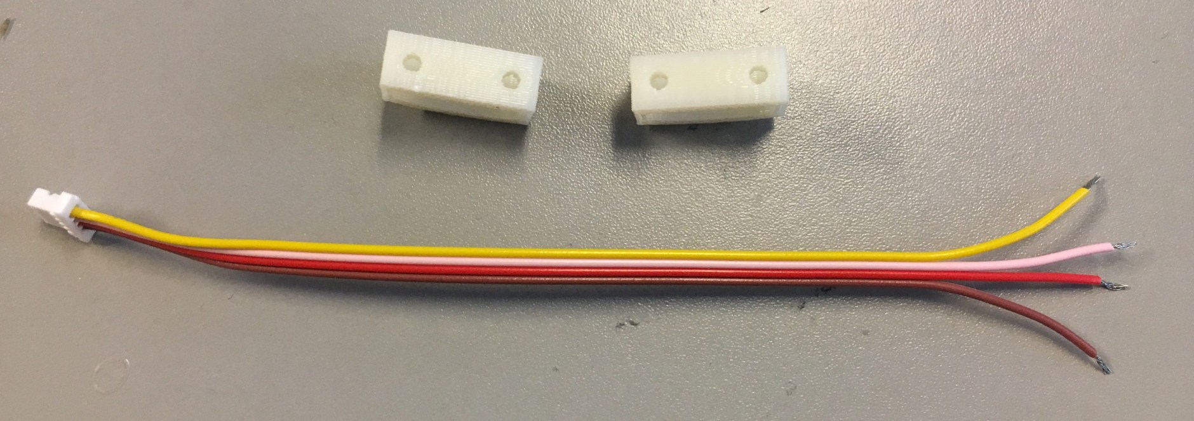
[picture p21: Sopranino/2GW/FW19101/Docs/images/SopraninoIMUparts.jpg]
T-Stick Sopranino IMU parts


The T-Stick Spatial orientation is dened as follows:

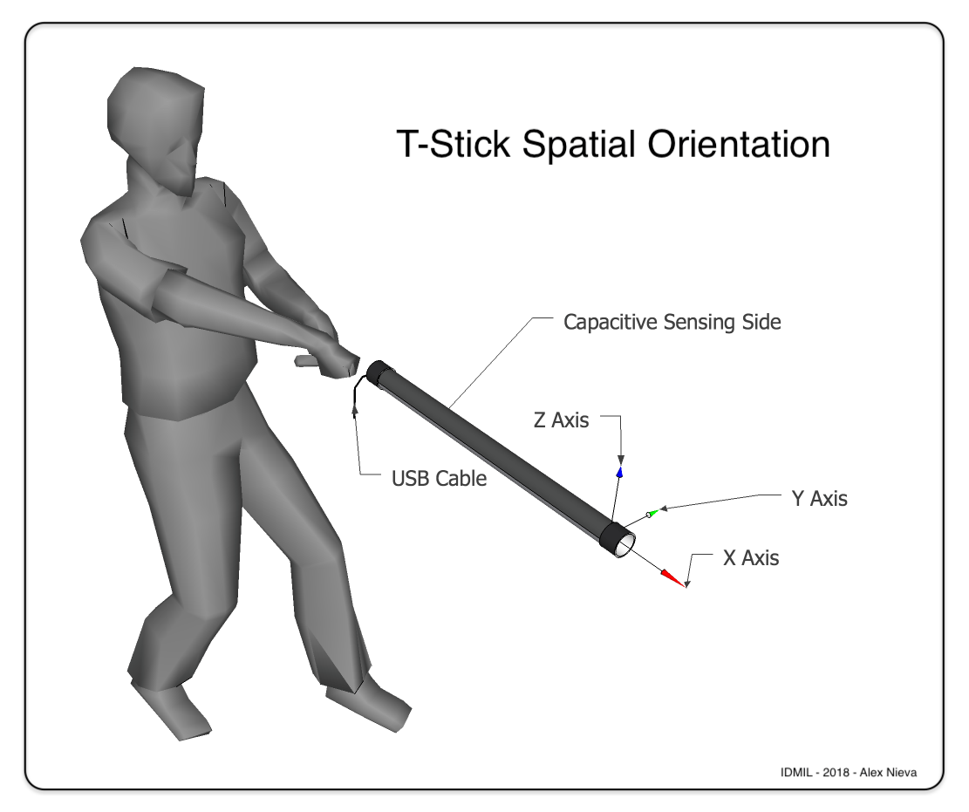
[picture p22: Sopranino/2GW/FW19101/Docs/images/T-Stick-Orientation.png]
T-Stick Sopranino orientation


Please, install the IMU so that this conguration is kept consistent will the design.

#### FSR and Piezo Electronics:

The Force Sensitive Resistor and the Piezoelectric sensor are glued to the frame with epoxy, superglue, or hot glue. 

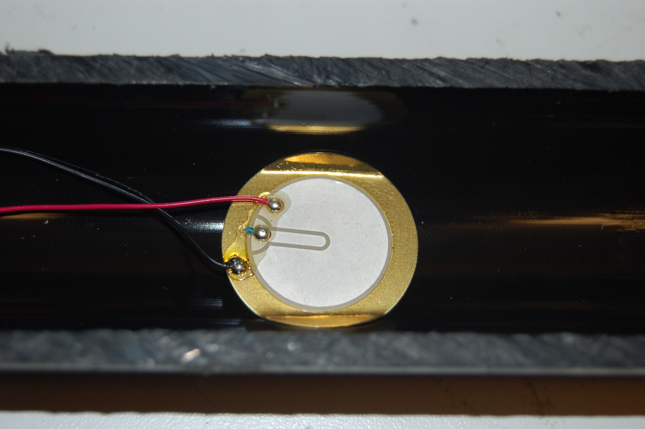
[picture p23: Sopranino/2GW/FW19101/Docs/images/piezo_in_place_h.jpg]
T-Stick Sopranino - piezo placement


The signal processing circuit is all analog and needs to be soldered to a perfboard. The piezoelectric circuit output is to be soldered to pin 32 of the ESP32 and the FSR circuit output to pin 33. Electronic building tools can be found in the Electronics Shop at the McGill Music Tech Department.

__Recommendation: Solder long cables to the FSR pins. They are very delicate. Put some heat shrink tube to reinforce the end of the fsr so it doesn’t break. If it breaks, it’s not repairable.__

Here’s the pinout for the LM358 opamp you will be using in the above circuit:

```
                      +--()--+
             Output A | 1   8| V+
    Inverting Input A | 2   7| Output B
Non-Inverting Input A | 3   6| Inverting Input B
                  GND | 4   5| Non-Inverting Input B
                      +------+
```

OBS: Don't forget to connect GND and V+.

##### Envelope Follower Circuit

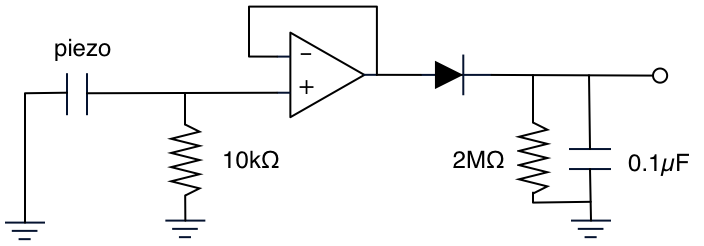
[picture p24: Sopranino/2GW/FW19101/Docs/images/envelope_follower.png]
T-Stick Sopranino - Envelope Follower Circuit


##### Voltage Divider Circuit

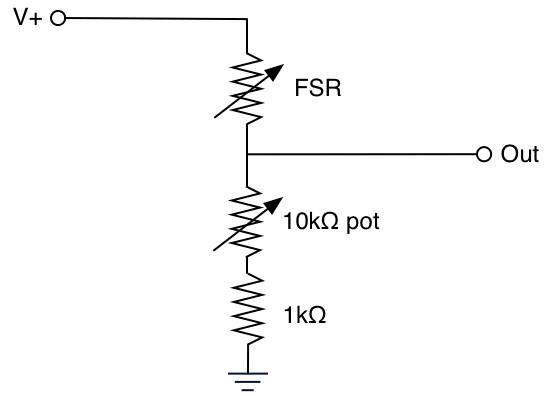
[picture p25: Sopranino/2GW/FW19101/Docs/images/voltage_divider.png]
T-Stick Sopranino - Voltage Divider Circuit T-Stick Sopranino - Envelope Voltage Divider


#### Microcontroller:

The microcontroller to be used with the T-Stick is the Lolin D32 PRO. You can check the tech specs at https://wiki.wemos.cc/products:d32:d32_pro.

#### Firmware:

Instructions to upload (flash) the T-Stick firmware and configuration files can be found [here](../README.md).

Read and follow __ALL__ the instructions before uploading it to the board.
There are some steps to prepare your machine and the ESP32 before flash it for the first time.

It is recommended to use the board test firmwares located at https://github.com/IDMIL/TStick/tree/master/Sopranino/2GW/FW19101/Tests to test the capsense board and the IMU after installing them.

Nightly builds and beta firmwares can be downloaded at https://github.com/edumeneses/TStick. Before using them, contact the IDMIL's lab team.

## More info:

Version 1.1: Edu Meneses - eduardo.meneses@mail.mcgill.ca\
Version 1.0: Created by: Alex Nieva - alex.nieva@mail.mcgill.ca

__Input Devices and Music Interaction Laboratory__
http://www.idmil.org\
Schulich School of Music\
McGill University\
550 Rue Sherbrooke Ouest, Suite 500\
Montreal, QC, H3A 1E\
Canada

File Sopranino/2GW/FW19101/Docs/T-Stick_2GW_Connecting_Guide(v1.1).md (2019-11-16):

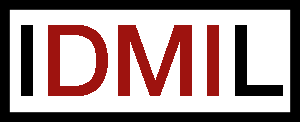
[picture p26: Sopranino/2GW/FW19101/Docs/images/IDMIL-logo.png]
IDMIL logo
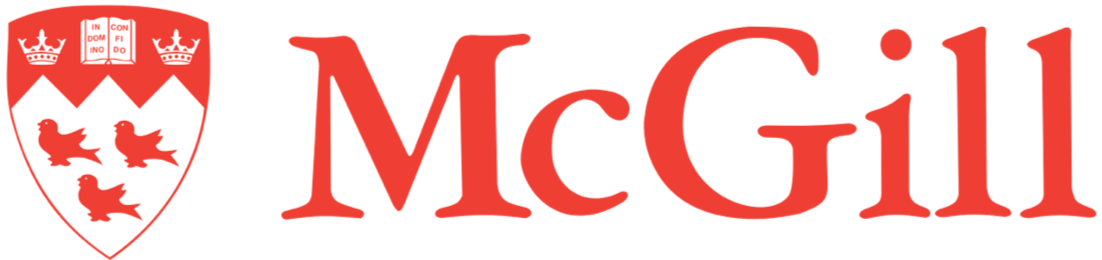
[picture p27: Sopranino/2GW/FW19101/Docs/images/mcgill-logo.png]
McGill logo
 &emsp; &emsp; &emsp; &emsp; 

# T-Stick Connecting Guide (v1.1)

This guide will show how to connect the T-Stick to a computer running macOS. This guide was tested on macOS Mojave, but it should work on older versions. To connect on Windows or Linux machines the procedure is similar, and this guide can serve as well.

Once this process is done, the T-Stick should connect to the computer automatically as long as both the computer and the T-Stick maintain the same IP address and use the same network.

The process, after learned, should take no more than 3min.

## 1-) Enter T-Stick setup, and connect to a network:

- Turn the T-Stick on:

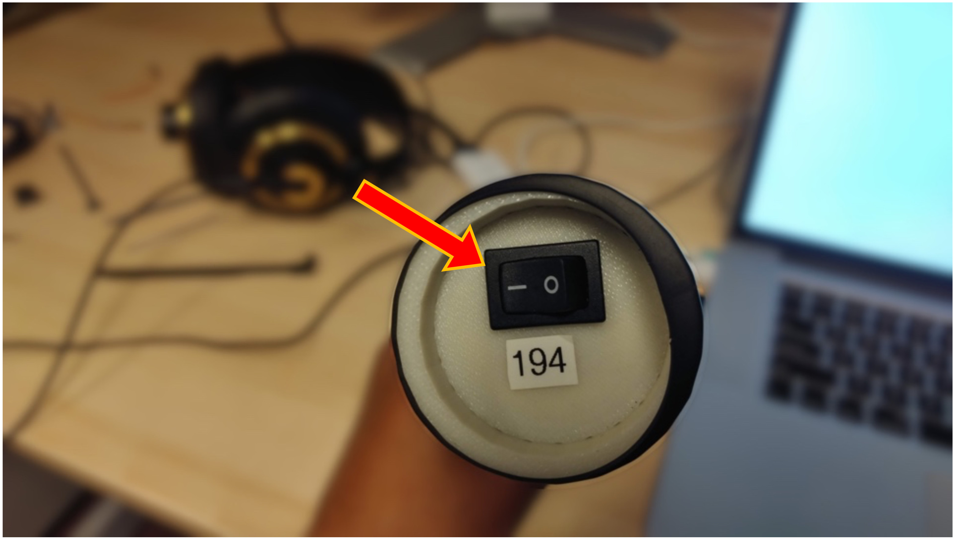
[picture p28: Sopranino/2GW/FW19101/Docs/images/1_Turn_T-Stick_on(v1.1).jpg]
Turn the T-Stick on


- Push the setup button to enter AP-mode. The T-Stick will then create an access point.

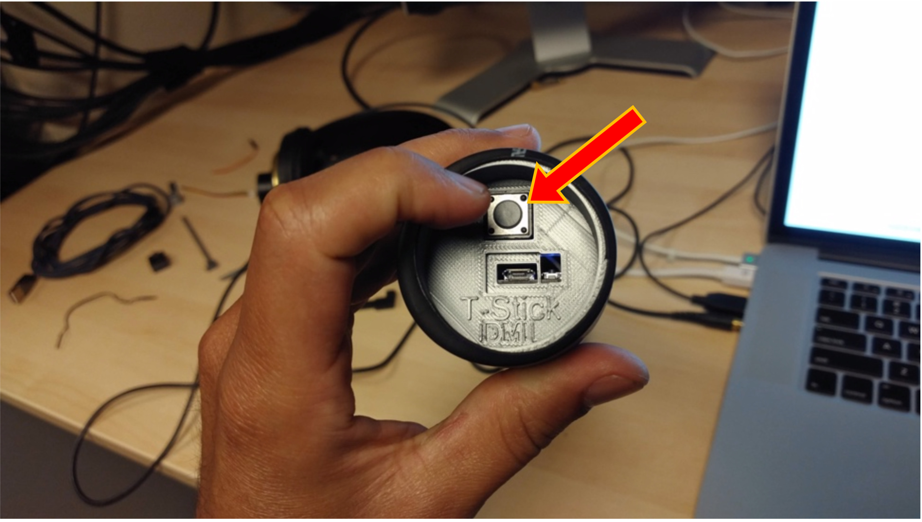
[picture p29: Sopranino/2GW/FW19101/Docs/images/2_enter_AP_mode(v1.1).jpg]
Enter AP mode


-  Connect to the T-Stick network:

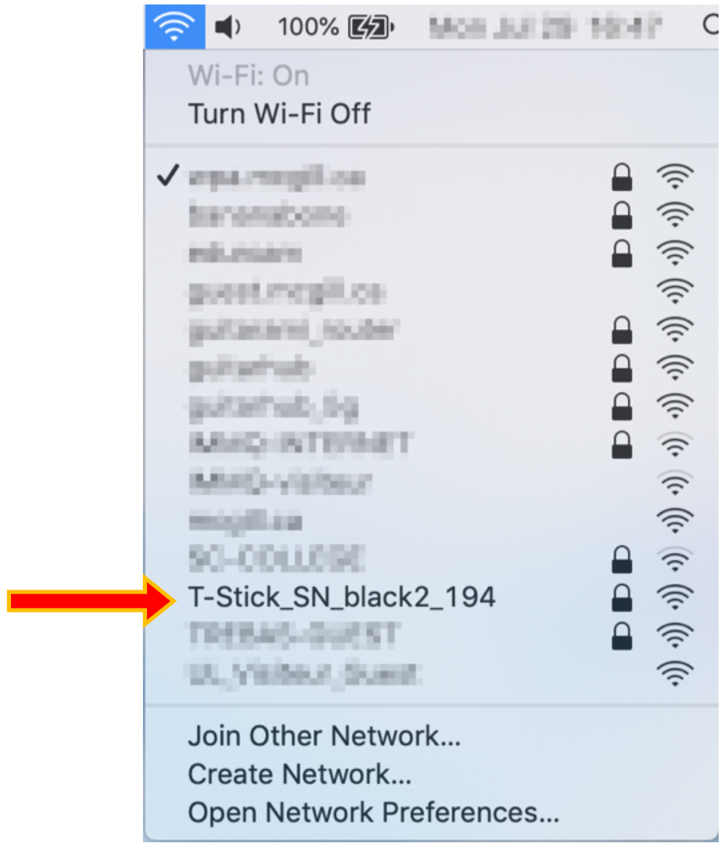
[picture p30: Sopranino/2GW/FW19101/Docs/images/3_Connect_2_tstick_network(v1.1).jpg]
Connect to the T-Stick network


- The setup portal should open automatically as soon as the computer connects to the T-Stick network. The page will inform the saved SSID and connection status. Click on Configuration.

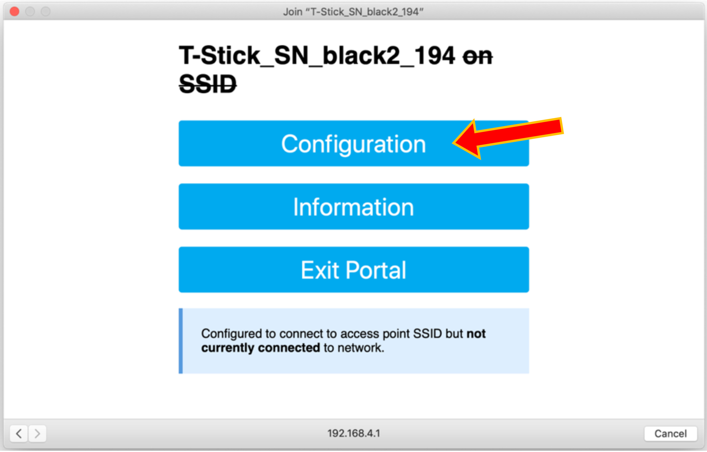
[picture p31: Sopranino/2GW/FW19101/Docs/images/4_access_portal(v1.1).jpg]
Access portal


- Choose the Wi-Fi network that will be used to connect the T-Stick and the computer. In this guide, we will use the _guitarami\_router_ network. Don’t forget to type the password (be
careful, the password is never hidden).

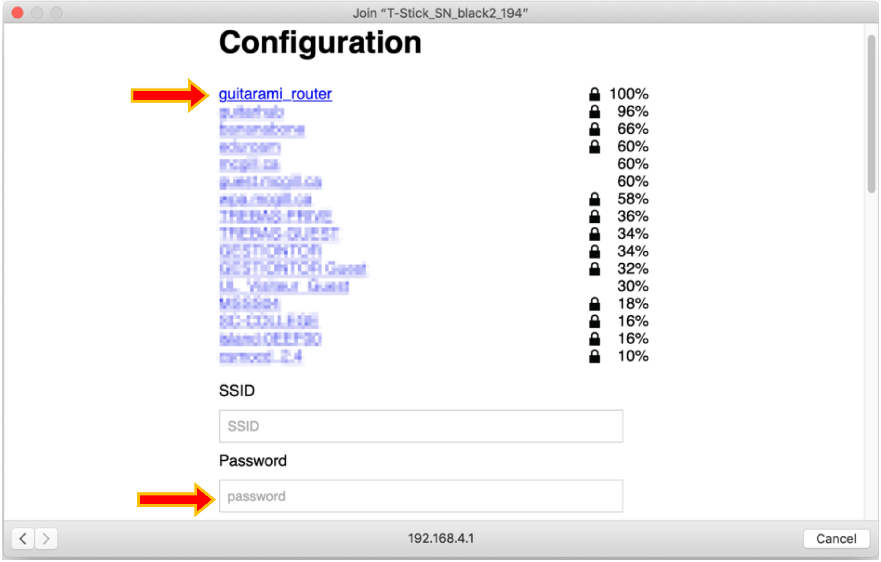
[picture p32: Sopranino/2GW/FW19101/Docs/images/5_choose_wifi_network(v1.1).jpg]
Choose wifi network


- Go to the end of the page and save your settings.

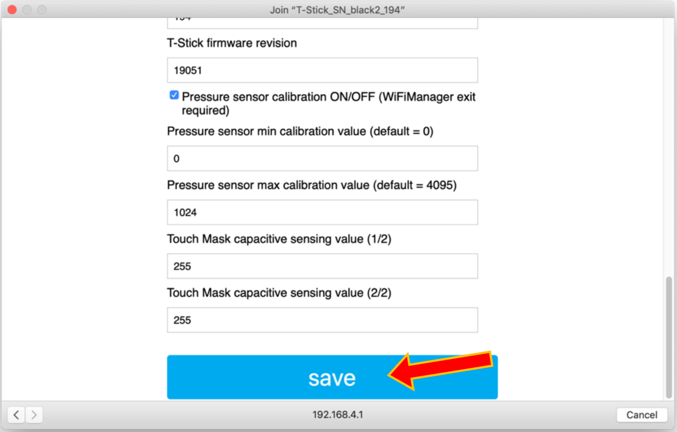
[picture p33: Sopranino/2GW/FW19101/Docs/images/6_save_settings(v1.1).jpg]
Save settings


- Wait at least 5 seconds before clicking on __how it went__. This will take you to the main setup page.

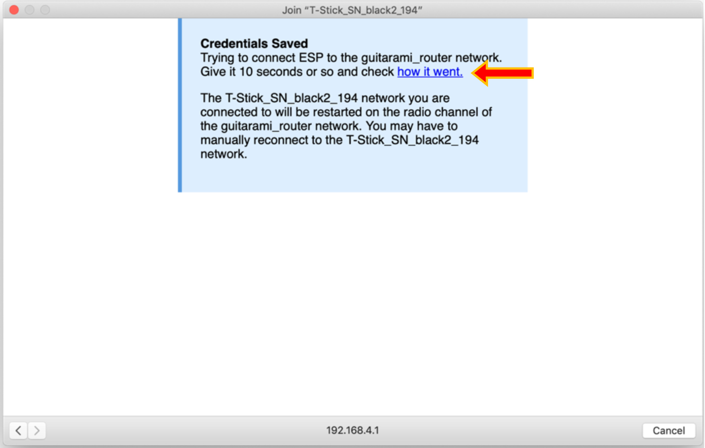
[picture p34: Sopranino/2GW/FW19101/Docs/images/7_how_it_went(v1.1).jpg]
How it went


- Check if the T-Stick is connected and if an IP was attributed to the instrument. Take note of the T-Stick IP address. Leave the portal open (do not hit __exit portal__).

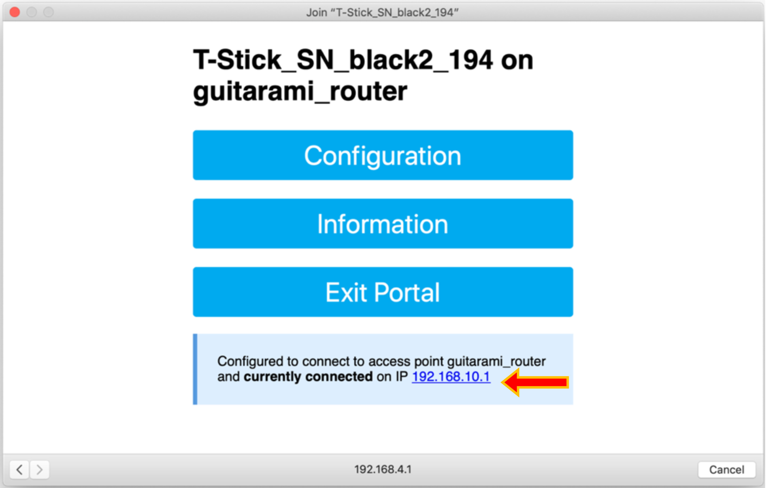
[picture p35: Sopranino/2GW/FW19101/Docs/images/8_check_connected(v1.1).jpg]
Check if connected


## 2-) Connect your computer/device to the same network, and access the T-Stick setup though the browser:

- Connect your computer to the same network the T-Stick currently is. In your case, we will connect to _guitarami\_router_.

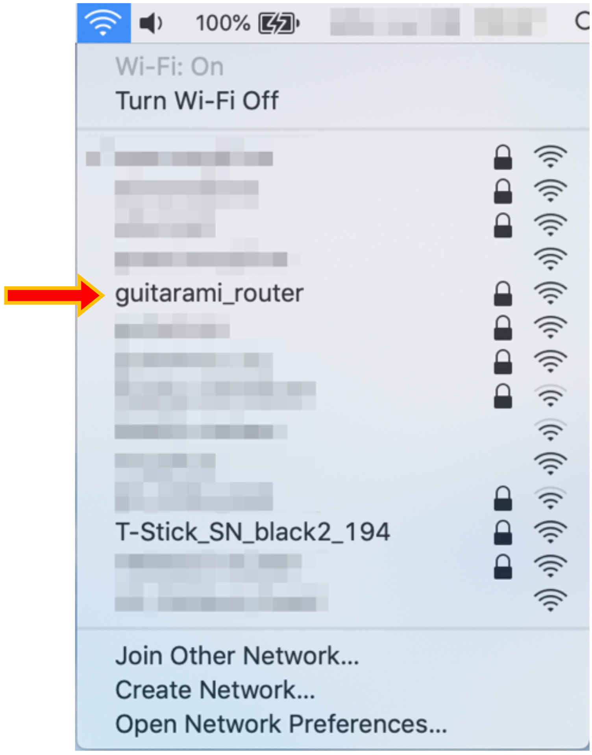
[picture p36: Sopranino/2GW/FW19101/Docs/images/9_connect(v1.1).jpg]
Connect


- Open your web browser and type the T-Stick IP address to access the setup portal using the chosen network.

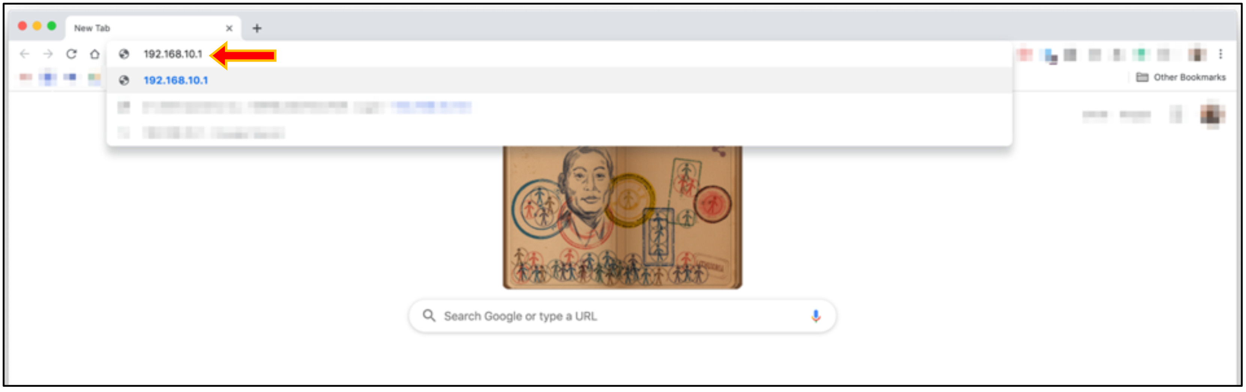
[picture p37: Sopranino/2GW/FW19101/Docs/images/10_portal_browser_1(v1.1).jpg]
Portal browser (1)


You will see the main portal screen through the web browser. Enter “Configuration” one more time.

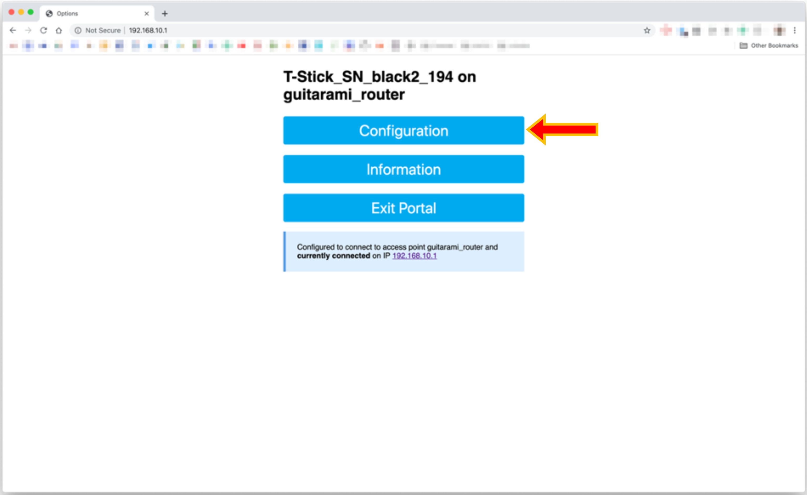
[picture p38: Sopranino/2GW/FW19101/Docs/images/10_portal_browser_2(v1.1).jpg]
Portal browser (2)


## 3-) Configure IP address/port to send OSC messages:

- Check the computer’s current IP (in macOS, you can hold the _Option_ key and hit the Wi-Fi icon to check that information). Copy the computer’s IP into the field “IP to send OSC messages”. Hit “Save”.

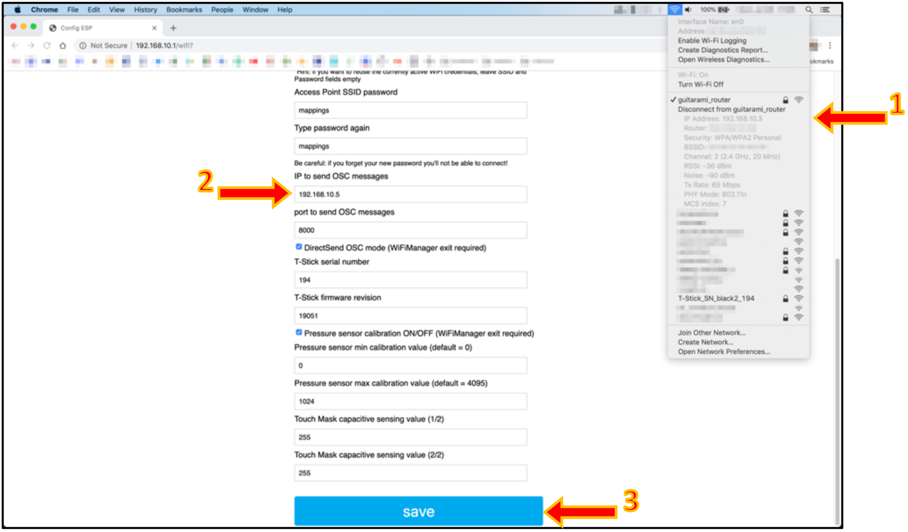
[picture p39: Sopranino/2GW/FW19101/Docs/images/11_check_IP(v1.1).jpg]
Check computer's IP


- Wait 5 more seconds and hit __how it went__:

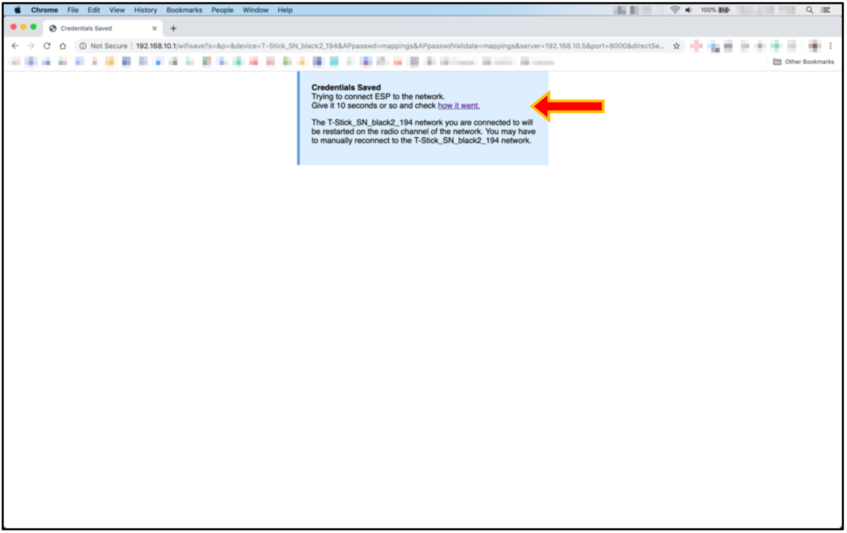
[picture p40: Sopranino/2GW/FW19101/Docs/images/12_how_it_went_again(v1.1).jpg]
How it went again


- Check if the T-Stick is connected and hit __Exit Portal__. The T-Stick will start sending information after the portal closes.

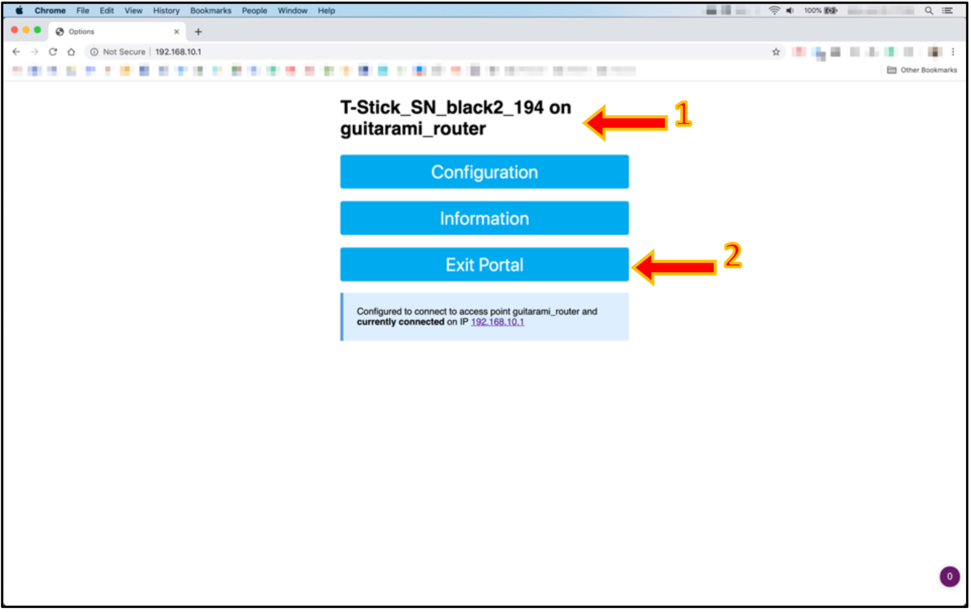
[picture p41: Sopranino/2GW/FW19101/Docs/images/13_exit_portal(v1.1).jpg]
Exit portal


- You can now close your browser and play the T-Stick.

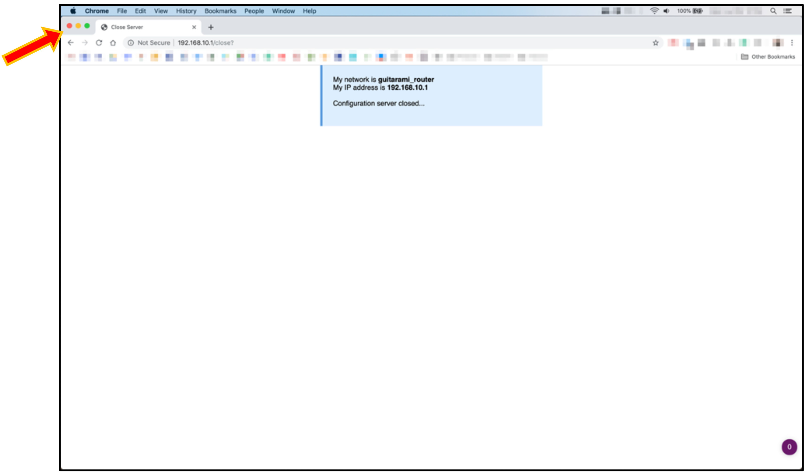
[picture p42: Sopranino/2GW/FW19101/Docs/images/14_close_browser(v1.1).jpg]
Close browser


## Guide info:

Version 1.1: (2019/10/27) Edu Meneses - eduardo.meneses@mail.mcgill.ca\
Version 1.0: (2019/08/28) Edu Meneses

__Input Devices and Music Interaction Laboratory__\
[http://www.idmil.org](http://www.idmil.org)\
Schulich School of Music\
McGill University\
550 Rue Sherbrooke Ouest, Suite 500\
Montreal, QC, H3A 1E\
Canada

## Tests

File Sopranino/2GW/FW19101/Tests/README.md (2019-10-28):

# T-Stick Module Tests

Contains both arduino sketches (may need to check library dependencies) and compiled binaries that can be uploaded directly using the [ESP flash download tool](https://www.espressif.com/en/support/download/other-tools) (Windows only), or the python script [esptool](https://github.com/espressif/esptool).

## Compiling from scratch

Alternatively, you can compile these examples in the Arduino IDE with the following libraries:

- Adafruit LSM9DS1
- Adafruit Sensor

Also, make sure you have the esp32 build system installed with the Arduino IDE!

# MAKE SURE YOU CONNECT THE SENSOR BOARDS IN THE RIGHT ORIENTATION!!!

## IMU-test:
- basic Adafruit LSM9DS1 test example. Spits out IMU data through serial port after initialization

## Capsense:
- Tests the Capsense board by itself. It should work with just the ESP32 board + Capsense board. Once the sketch is running, you should be able to rub your fingers on the pin pads where the copper strips will be connected to, and see the finger touch detected through packed bytes sent via the serial port.

## CapsenseIMU:
- Combined test for both boards.

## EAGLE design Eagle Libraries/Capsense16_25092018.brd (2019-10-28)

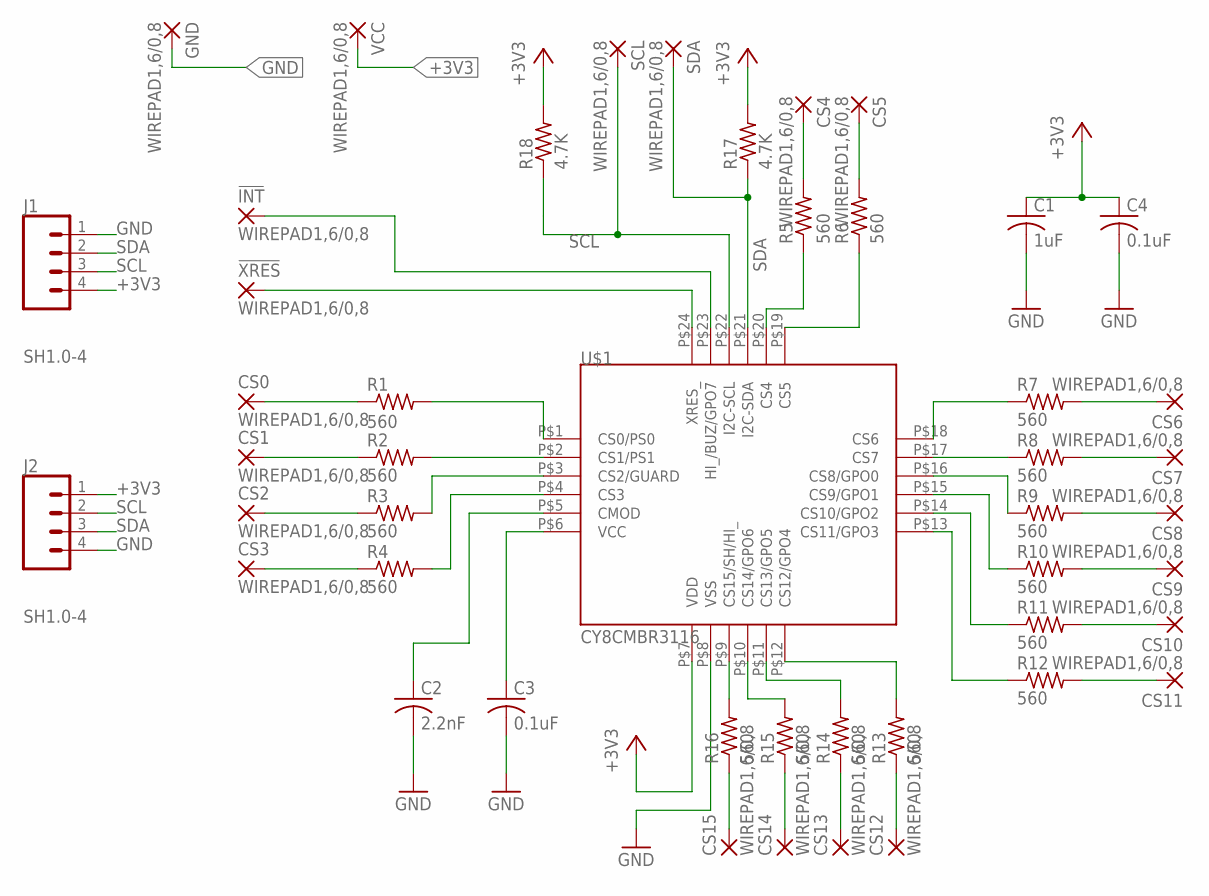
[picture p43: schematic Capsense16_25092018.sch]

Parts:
!INT!: WIREPAD1,6/0,8; 1,6/0,8
!XRES!: WIREPAD1,6/0,8; 1,6/0,8
C1: 1uF; C0603
C2: 2.2nF; C0603
C3, C4: 0.1uF; C0603
CS0, CS1, CS2, CS3, CS4, CS5, CS6, CS7, CS8, CS9, CS10, CS11, CS12, CS13, CS14, CS15: WIREPAD1,6/0,8; 1,6/0,8
GND: WIREPAD1,6/0,8; 1,6/0,8
J1, J2: SH1.0-4; JST-4-SMD-HORI-1.0MM
R1, R2, R3, R4, R5, R6, R7, R8, R9, R10, R11, R12, R13, R14, R15, R16: 560; R0603
R17, R18: 4.7K; R0603
SCL: WIREPAD1,6/0,8; 1,6/0,8
SDA: WIREPAD1,6/0,8; 1,6/0,8
U$1: CY8CMBR3116
VCC: WIREPAD1,6/0,8; 1,6/0,8

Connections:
+3V3: C1.1, C4.1, J1.4, J2.1, R17.2, R18.2, U$1.P$7 (VDD), VCC.1
GND: C1.2, C2.2, C3.2, C4.2, GND.1, J1.1, J2.4, U$1.P$8 (VSS)
unnamed: R7.1, U$1.P$18 (CS6)
unnamed: R8.1, U$1.P$17 (CS7)
unnamed: R9.1, U$1.P$16 (CS8/GPO0)
unnamed: R10.1, U$1.P$15 (CS9/GPO1)
unnamed: R11.1, U$1.P$14 (CS10/GPO2)
unnamed: R12.1, U$1.P$13 (CS11/GPO3)
unnamed: R6.1, U$1.P$19 (CS5)
unnamed: R5.1, U$1.P$20 (CS4)
unnamed: R1.2, U$1.P$1 (CS0/PS0)
unnamed: R2.2, U$1.P$2 (CS1/PS1)
unnamed: R3.2, U$1.P$3 (CS2/GUARD)
unnamed: R4.2, U$1.P$4 (CS3)
unnamed: R13.2, U$1.P$12 (CS12/GPO4)
unnamed: R14.2, U$1.P$11 (CS13/GPO5)
unnamed: R15.2, U$1.P$10 (CS14/GPO6)
unnamed: R16.2, U$1.P$9 (CS15/SH/HI_)
unnamed: C2.1, U$1.P$5 (CMOD)
unnamed: C3.1, U$1.P$6 (VCC)
unnamed: !XRES!.1, U$1.P$24 (XRES_)
unnamed: CS0.1, R1.1
unnamed: CS1.1, R2.1
unnamed: CS2.1, R3.1
unnamed: CS3.1, R4.1
unnamed: CS15.1, R16.1
unnamed: CS14.1, R15.1
unnamed: CS13.1, R14.1
unnamed: CS12.1, R13.1
unnamed: CS11.1, R12.2
unnamed: CS10.1, R11.2
unnamed: CS9.1, R10.2
unnamed: CS8.1, R9.2
unnamed: CS7.1, R8.2
unnamed: CS6.1, R7.2
unnamed: CS4.1, R5.2
unnamed: CS5.1, R6.2
unnamed: !INT!.1, U$1.P$23 (HI_/BUZ/GPO7)
SCL: J1.3, J2.2, R18.1, SCL.1, U$1.P$22 (I2C-SCL)
SDA: J1.2, J2.3, R17.1, SDA.1, U$1.P$21 (I2C-SDA)

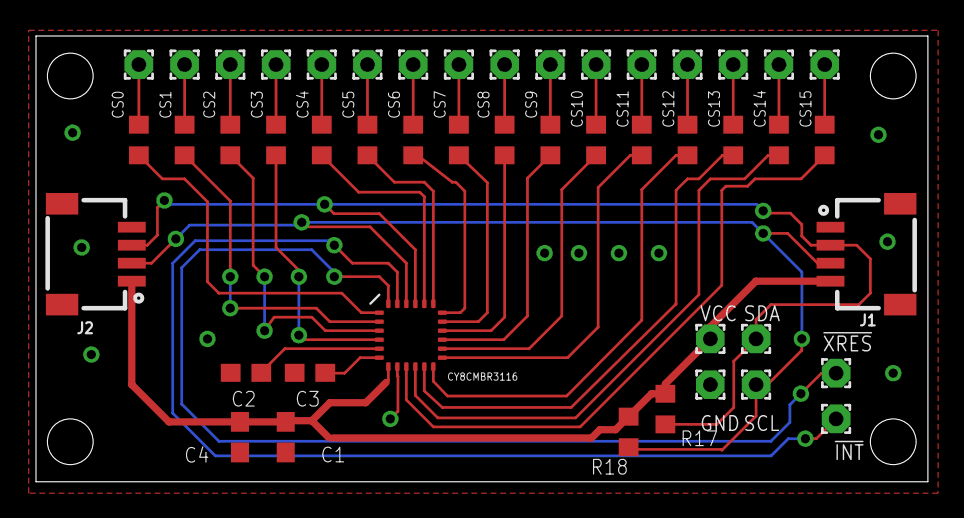
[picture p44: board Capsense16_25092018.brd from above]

Board: 2 copper layers, 49.5 x 24.8 mm, 47 parts (0 on the bottom side), 40 nets.

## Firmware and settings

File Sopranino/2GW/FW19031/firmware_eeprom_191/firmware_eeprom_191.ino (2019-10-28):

//********************************************************************************//
//  Sopranino T-Stick 2GW - LOLIN D32 PRO - USB -WiFi                             //
//  Input Devices and Music Interaction Laboratory                                //
//  Created:  February 2018 by Alex Nieva                                         //
//            March 2019 by Edu Meneses - version 19031 (2019-03.v1)              //
//  Notes   : Based on test program for reading CY8C201xx using I2C               //
//            by Joseph Malloch 2011                                              //
//                                                                                //
//            Adapted to work with Arduino IDE 1.8.8 and T-Stick Sopranino 2GW    //
//********************************************************************************//

//**************************************************//
// WiFi32Manager - For use with ESP8266 or ESP32    //
//                                                  //
// Created originally for the T-Stick project:      //
// http://www-new.idmil.org/project/the-t-stick/    //
//                                                  //
// This code uses code (fork) of 3 other projects:  //
// https://github.com/kentaylor/WiFiManager         //
// https://github.com/tzapu/WiFiManager             //
// https://github.com/zhouhan0126/WIFIMANAGER-ESP32 //
//                                                  //
// Edu Meneses - IDMIL - Mar 2019                   //
//**************************************************//


// READ ALL DEPENDENCIES AND OBSERVATIONS BEFORE UPLOAD !!!!!!!!
// ---- --- ------------ --- ------------ ------ ------ 
// ---- --- ------------ --- ------------ ------ ------ 

// FIRMWARE VERSION: 19051

// IMPORTANT: You need to upload a blank file (data/config.json) into ESP32 filesystem. 
// Follow the instructions at https://github.com/me-no-dev/arduino-esp32fs-plugin

// DEPENDENCIES:
// esp32 board library (add url to preferences; install via board manager)
// esp8266 board library (add url to preferences; install via board manager)
// Wifimanager https://github.com/edumeneses/WiFi32Manager
// Adafruit_LSM9DS1 (library manager)
// ArduinoJSON (library manager - need version 5.13.5; 6.x will not work)
// OSC - https://github.com/CNMAT/OSC (library manager)

//  OBS:
//  1-) Use esp32 1.0.1 or newer (https://github.com/espressif/arduino-esp32/releases)
//  2-) For esp32 1.0.2 ESP32 has problems saving SSID. Follow instructions: https://github.com/edumeneses/WiFi32Manager
//  2-) Also install ESP8266 board library even if you'll use the ESP32 (https://github.com/esp8266/Arduino)
//  3-) Some used library doesn't allow the creation of functions with "setup" in the name
//  4-) Board currently in use: LOLIN D32 PRO
//  5-) Dont forget to change T-Stick Specific Definitions

#include <FS.h>  // this needs to be first, or it all crashes and burns...

#define ESP32; // define ESP8266 or nothing (to use ESP32) 
//#define ESP8266;

#if defined(ESP32)
#include "SPIFFS.h"
#endif

/* You only need to format SPIFFS the first time you run a
   test or else use the SPIFFS plugin to create a partition
   https://github.com/me-no-dev/arduino-esp32fs-plugin */
//#define FORMAT_SPIFFS_IF_FAILED true

#include <WiFi32Manager.h> // https://github.com/edumeneses/WiFi32Manager
// already includes:
// Wifi.h (https://github.com/esp8266/Arduino) or ESP8266WiFi.h (https://github.com/esp8266/Arduino)
// AND
// WebServer.h or ESP8266WebServer.h
// AND
// DNSServer.h

//#include "src/DNSServer/DNSServer.h"
//#include "src/WebServer/WebServer.h"

#include <ArduinoJson.h>  // https://github.com/bblanchon/ArduinoJson
// Wifi.h requires ArduinoJson 5.13.5

#include <Wire.h>
#include <WiFiUdp.h>
#include <OSCMessage.h> // https://github.com/CNMAT/OSC

#include <SPI.h>
#include <Adafruit_LSM9DS1.h> // https://github.com/adafruit/Adafruit_LSM9DS1
#include <Adafruit_Sensor.h> // https://github.com/adafruit/Adafruit_Sensor


//////////////////////////////////
//////////////////////////////////
// T-Stick Specific Definitions //
//////////////////////////////////
//////////////////////////////////


unsigned int infoTstick[2] = {191, 19051};    // serial number and firmware revision
char author[20] = "Alex Nieva"; // DON'T FORGET TO CHANGE ALSO IN WiFi.ino, LINE 132
char nickname[10] = "SN_black"; // sopranino (SN), soprano (SO), tenor (TE), etc.
char APpasswd[15] = "mappings"; // standard AP password

char device[25] = "T-Stick_";
char APpasswdValidate[15];
char APpasswdTemp[15];
int directSendOSC = 0;
char directSendOSCCHAR[3] = "0";
char infoTstickCHAR0[6]; // same serial # to be saved in json
char infoTstickCHAR1[6]; // same firmware # to be saved in json
int calibrate = 0;
char calibrateCHAR[5] = "0"; // same calibrate # to be saved in json
char stored_ssid[20];
char stored_psk[20];

// Debug & calibration definitions
#define DEBUG true
#define CALIB false

//////////////////////////
// Capsense Definitions //
//////////////////////////

#define SENSOR_EN 0x00
#define FSS_EN 0x02
#define SENSITIVITY0 0x08
#define SENSITIVITY1 0x09
#define SENSITIVITY2 0x0A
#define SENSITIVITY3 0x0B
#define DEVICE_ID 0x90    // Should return 0xA05 (returns 2 bytes)
#define FAMILY_ID 0x8F
#define SYSTEM_STATUS 0x8A
#define I2C_ADDR 0x37     // Should return 0x37
#define REFRESH_CTRL 0x52
#define SENSOR_EN 0x00    // We should set it to 0xFF for 16 sensors
#define BUTTON_STAT 0xAA  // Here we red the status of the sensors (2 bytes)
#define CTRL_CMD 0x86     // To configure the Capsense
#define CTRL_CMD_STATUS 0x88
#define CTRL_CMD_ERROR 0x89
#define BUTTON_LBR 0x1F
#define SPO_CFG 0x4C      //CS15 configuration address
#define GPO_CFG 0x40
#define CALC_CRC 0x94
#define CONFIG_CRC 0x7E

//////////////////////
// WiFi Definitions //
//////////////////////

//define your default values here, if there are different values in config.json, they are overwritten.
IPAddress oscEndpointIP(192, 168, 5, 1); // remote IP of your computer
unsigned int oscEndpointPORT = 57120; // remote port to receive OSC
char oscIP[17] = "192.168.10.1";
char oscPORT[7] = "8000";
int timeout1 = 5000; bool timeout1check = false;
WiFiUDP oscEndpoint;            // A UDP instance to let us send and receive packets over UDP
const unsigned int portLocal = 8888;       // local port to listen for OSC packets (actually not used for sending)
bool udpConnected = false;
bool sendOSC = true;
static int bufferFromHost[4] = {0, 0, 0, 0};
int interTouch[2];
char zero[3] = "0";
char one[3] = "1";


//////////////////////////
// LSM9DS1 Library Init //
//////////////////////////

// Adafruit library
Adafruit_LSM9DS1 lsm = Adafruit_LSM9DS1();

float deltat = 0.0f;        // integration interval for both filter schemes
uint32_t lastUpdate = 0;    // used to calculate integration interval
uint32_t Now = 0;           // used to calculate integration interval
float q[4] = {1.0f, 0.0f, 0.0f, 0.0f};    // vector to hold quaternion
float pitch, yaw, roll, heading;
float outAccel[3] = {0, 0, 0};
float outGyro[3] = {0, 0, 0};
float outMag[3] = {0, 0, 0};

// global constants for 9 DoF fusion and AHRS (Attitude and Heading Reference System)
#define GyroMeasError PI * (40.0f / 180.0f)       // gyroscope measurement error in rads/s (shown as 3 deg/s)
#define GyroMeasDrift PI * (0.0f / 180.0f)      // gyroscope measurement drift in rad/s/s (shown as 0.0 deg/s/s)
// There is a tradeoff in the beta parameter between accuracy and response speed.
// In the original Madgwick study, beta of 0.041 (corresponding to GyroMeasError of 2.7 degrees/s) was found to give optimal accuracy.
// However, with this value, the LSM9SD0 response time is about 10 seconds to a stable initial quaternion.
// Subsequent changes also require a longish lag time to a stable output, not fast enough for a quadcopter or robot car!
// By increasing beta (GyroMeasError) by about a factor of fifteen, the response time constant is reduced to ~2 sec
// I haven't noticed any reduction in solution accuracy. This is essentially the I coefficient in a PID control sense;
// the bigger the feedback coefficient, the faster the solution converges, usually at the expense of accuracy.
// In any case, this is the free parameter in the Madgwick filtering and fusion scheme.
#define beta sqrt(3.0f / 4.0f) * GyroMeasError   // compute beta
#define zeta sqrt(3.0f / 4.0f) * GyroMeasDrift   // compute zeta, the other free parameter in the Madgwick scheme usually set to a small or zero value


////////////////////////////
// Sketch Output Settings //
////////////////////////////

#define PRINT_CALCULATED
//#define PRINT_RAW
#define PRINT_SPEED 20 // 250 ms between prints
static unsigned long lastPrint = 0; // Keep track of print time

// Earth's magnetic field varies by location. Add or subtract
// a declination to get a more accurate heading. Calculate
// your's here:
// http://www.ngdc.noaa.gov/geomag-web/#declination
#define DECLINATION -14.34 // Declination (degrees) in Montreal, QC.


//////////////
// defaults //
//////////////

int piezoPin = 32;
int pressurePin = 33;
int ledPin = 5; //changed for The thing dev during testing
int ledStatus = 0;
int ledTimer = 1000;
byte touch[2] = {0, 0};
int touchMask[2] = {255, 255};
char touchMaskCHAR0[7] = "255"; // same cal # to be saved in json
char touchMaskCHAR1[7] = "255"; // same cal # to be saved in json
unsigned int calibrationData[2] = {0, 1024};
char calibrationDataCHAR0[6] = "0"; // same cal # to be saved in json
char calibrationDataCHAR1[6] = "1024"; // same cal # to be saved in json
unsigned int pressure = 0;
uint32_t dataTransferRate = 20; // sending data at 50Hz
uint32_t deltaTransferRate = 0;
const int buttonPin = 15;



////////////////////////
//control definitions //
////////////////////////

unsigned long then = 0;
unsigned long now = 0;
unsigned long started = 0;
unsigned long lastRead = 0;
byte interval = 10;
byte touchInterval = 15;
unsigned long lastReadSensors = 0;
int buttonState = 0;         // variable for reading the pushbutton status


void setup() {

  
  //wifiManager.setDebugOutput(true);

  Serial.begin(115200);
  if (DEBUG == true) {
    Serial.println("\n Starting");
  }

  // Converting T-Stick info into char (str)
  itoa(infoTstick[0], infoTstickCHAR0, 10);
  itoa(infoTstick[1], infoTstickCHAR1, 10);
  strcat(device, nickname);
  strcat(device, "_");
  strcat(device, infoTstickCHAR0);
  memcpy(APpasswdValidate, APpasswd, 15);
  memcpy(APpasswdTemp, APpasswd, 15);
  
  // Starting WiFiManager in Trigger Mode
  Wifimanager_init(DEBUG);

  #if defined(ESP8266)
  WiFi.hostname(device);
  #else
  WiFi.setHostname(device);
  #endif

  initIMU();

  initCapsense();

  pinMode(ledPin, OUTPUT);
  pinMode(buttonPin, INPUT_PULLUP);

  delay(100);

  if (DEBUG == true) {
    Serial.println("Setup complete.");
  }

  #if defined(ESP32) 
    if (WiFi.status() != WL_CONNECTED) {
      if (DEBUG == true) {Serial.println("ESP32 3rd attempt to connect");}
      WiFi.begin(stored_ssid, stored_psk);
      if (DEBUG == true) {
        if (WiFi.status() != WL_CONNECTED) {Serial.println("Connected on 3rd attempt");}
        else {Serial.println("Failed to connect, finishing setup anyway");}
      }
    }
  #endif
  
}

void loop() {

  
  // Calling WiFiManager configuration portal
  buttonState = digitalRead(buttonPin);
  //if ( outAccel[0] > 1 && interTouch[0] == 9 && interTouch[1] == 144 ) {
  if ( buttonState == LOW ) {
    digitalWrite(ledPin, HIGH);
    Wifimanager_portal(device, APpasswd, true, DEBUG);
  }

  byte dataRec = OSCMsgReceive();

  if (dataRec) { //Check for OSC messages from host computers
    if (DEBUG) {
      Serial.println();
      for (int i = 0; i < 4; i++) {
        Serial.printf("From computer %d: ", i); Serial.println(bufferFromHost[i]);
      }
      Serial.println();
    }
    char message = bufferFromHost[0];

    OSCMessage msg0("/information");

    switch (message) {
      case 's': // start message,
        msg0.add(infoTstick[0]);
        msg0.add(infoTstick[1]);
        oscEndpoint.beginPacket(oscEndpointIP, oscEndpointPORT);
        msg0.send(oscEndpoint);
        oscEndpoint.endPacket();
        msg0.empty();

        started = millis();
        break;
      case 'x': // stop message,
        started = 0;
        break;
      case 'c': // calibrate message
        switch (bufferFromHost[1]) {
          case 1: // FSR calibration
            calibrationData[0] = bufferFromHost[2];
            calibrationData[1] = bufferFromHost[3];
            calibrate = 1;
            bufferFromHost[1] = 0;
            bufferFromHost[2] = 0;
            bufferFromHost[3] = 0;
            break;
          default:
            calibrate = 0;
            break;
        }
        break;
      case 'w':     //write settings
        switch ((char)bufferFromHost[1]) {
          case 'i': //write info
            infoTstick[0] = bufferFromHost[2];
            infoTstick[1] = bufferFromHost[3];
            bufferFromHost[1] = 0;
            bufferFromHost[2] = 0;
            bufferFromHost[3] = 0;
            break;
          case 'T': //write touch mask
            touchMask[0] = bufferFromHost[2];
            touchMask[1] = bufferFromHost[3];
            bufferFromHost[1] = 0;
            bufferFromHost[2] = 0;
            bufferFromHost[3] = 0;
            break;
          case 'w': // write settings to memory (json)
            save_to_json(DEBUG);
            bufferFromHost[1] = 0;
            break;
          case 'r': // sending the config info trough OSC
            msg0.add(infoTstick[0]);
            msg0.add(infoTstick[1]);
            msg0.add(calibrate);
            msg0.add(calibrationData[0]);
            msg0.add(calibrationData[1]);
            msg0.add(touchMask[0]);
            msg0.add(touchMask[1]);
            oscEndpoint.beginPacket(oscEndpointIP, oscEndpointPORT);
            msg0.send(oscEndpoint);
            oscEndpoint.endPacket();
            msg0.empty();
            bufferFromHost[1] = 0;
            break;
          default:
            break;
        }
      default:
        break;
    }
  }

  now = millis();

  if (directSendOSC == 0) {
    if (now < started + 2000) { // needs a ping/keep-alive every 2 seconds or less or will time-out
      TStickRoutine();
    }
    else { // runs when there's no ping/keep-alive
      now = millis();

      // Calling configuration portal if the T-Stick is disconnected
//      if (millis() - lastRead > interval) {
//        lastRead = millis();
//        pressure = analogRead(pressurePin);
//        //if (DEBUG) {Serial.print("Pressure sensor: "); Serial.println(pressure);}
//      }
      //if ( pressure > 4090 ) {
      if ( buttonState == LOW ) {
        digitalWrite(ledPin, HIGH);
        Wifimanager_portal(device, APpasswd, true, DEBUG);
      }
      else {
        if ((now - then) > ledTimer) {
          ledBlink();
          then = now;
        }
        else if ( then > now) {
          then = 0;
        }
      }
    }
  } else {
    TStickRoutine();
  }

} // END LOOP

void ledBlink() {
  ledStatus = (ledStatus + 1) % 2;
  digitalWrite(ledPin, ledStatus);
}

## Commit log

2019-02-22 - New firmware (19021) added for T-Stick sopranino 181 - Pure Data drivers for T-Sticks 173 and 181
    [Sopranino2GW-181.sch]
2019-05-16 longer pads for capsense in library; fixed pin orientation on board to match Lolin connector
    [Capsense16_25092018.brd, Capsense16_25092018.sch]
2019-05-24 Update Eagle library
    [Capsense16_25092018.brd, Capsense16_25092018.sch]
2019-07-05 firmware updates and caps
    [2019_07_05_T-Stick_battery_cap(no_number).stl, 2019_07_05_T-Stick_bed_cap.stl, 2019_07_05_T-Stick_esp_cap.stl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]
2019-07-05 caps update - add tstick number
    [2019_07_05_tstick_cap v71(Fusion360).f3d, battery_cap.stl, esp_bed.stl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]
2019-09-05 switch to bundled approach, remove speed limit
2019-09-24 fixed JST connector silkscreen labels
    [Capsense16_25092018.brd]
2019-10-24 capsense + imu test
2019-10-26 docs, new firmware(not working yet), folder organization
    [2019_07_05_T-Stick_battery_cap(no_number).stl, 2019_07_05_T-Stick_bed_cap.stl, 2019_07_05_T-Stick_esp_cap.stl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]
2019-11-09 updated battery cap
    [2019_07_05_T-Stick_battery_cap(no_number).stl, 2019_11_09_T-Stick_battery_cap(19X).stl, 2019_11_09_tstick_cap v74(Fusion360).f3d]
